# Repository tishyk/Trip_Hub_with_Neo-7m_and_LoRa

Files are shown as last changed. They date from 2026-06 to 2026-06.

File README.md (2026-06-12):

# LoRa GPS Mesh — off-grid trackers, chat & a live map dashboard

         

> A self-contained LoRa mesh that tracks GPS journeys, detects trips, relays
> chat, and reports device health — **with no internet, SIM card or cellular
> anywhere in the data path** — then visualises everything on a web map. This is cheap to build and easy to use.

<p align="center">
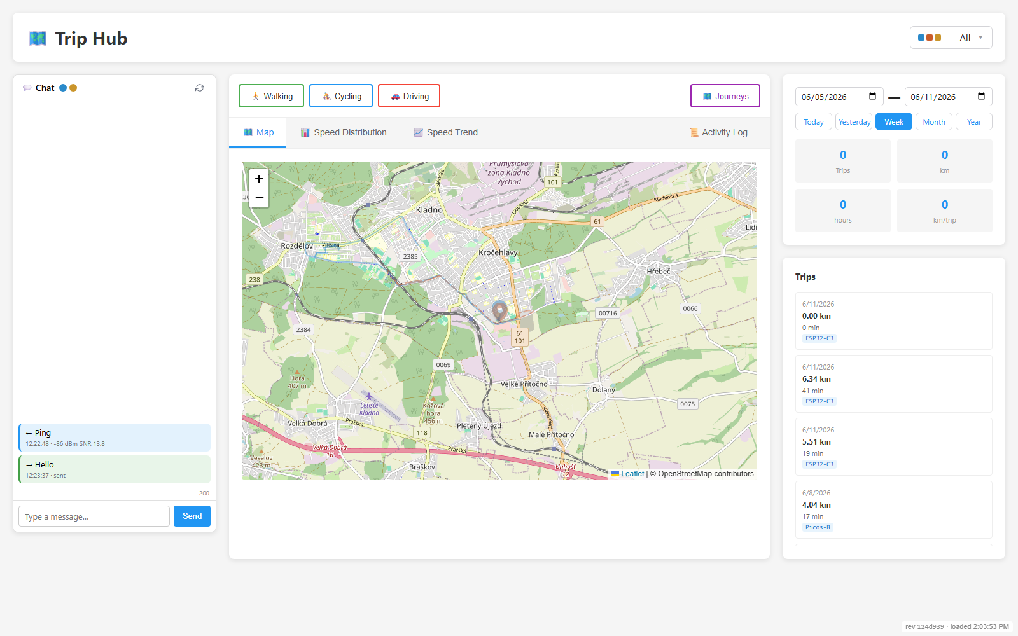
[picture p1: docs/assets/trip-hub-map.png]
Trip Hub web dashboard — live map with trip polylines, chat and presence
  
</p>

<p align="center">
  <em>The Trip Hub dashboard: show a live location, store a trip data points and build polinlines for 3 different types of movement, show stats, has an embedded chat panel with encripted comunication and live device-presence dots — fed entirely by 434 MHz LoRa radio. Support multiple devices with all actions logging</em>
</p>

---

## Why this exists

This is a working reference design for a question clients ask all the time:

> *“I want GPS tracking and a bit of messaging over long range, off the grid,
> shown on a web page — what can you actually build?”*

This repo is the answer, end to end: **four heterogeneous devices** speaking one
encrypted LoRa protocol, a Raspberry Pi gateway (or almost any other Linux OS), and **two web interfaces**
(an on-device captive chat UI and a full map/analytics dashboard). It’s built
from inexpensive, off-the-shelf modules and documents every wire format,
pinout and design decision so you can lift any piece into your own product.

It deliberately spans **three different runtimes** — Arduino C++, MicroPython
and CPython — to show the same radio protocol implemented natively on each, and
how a mixed fleet interoperates.

---

## Highlights

- 📡 **Long-range, license-free radio.** SX127x LoRa @ 434 MHz, SF9/BW125 —
  kilometres of range at a few hundred bits/s, no infrastructure.
- 🔒 **Encrypted on the air.** AES-128 on every packet; same key across the fleet.
- 🛰️ **GPS trip detection.** On-device state machine classifies walking /
  cycling / driving, detects start & stop, and logs dense tracks to flash.
- 🔁 **Store-and-forward sync.** Trackers buffer trips offline and stream them
  to the hub over a reliable query/response protocol when back in range.
- 💬 **Chat over LoRa.** Phone → on-device web UI → LoRa → hub, and back.
- 🟢 **Live device presence.** Every node heartbeats once a minute; the fleet
  (and both web UIs) shows who’s online, with signal strength.
- 🗺️ **Web dashboard.** Leaflet map of every journey, speed analytics, an
  activity log of raw radio traffic, and the chat panel — served from a Pi.
- 🧩 **Three runtimes, one protocol.** Arduino C++ (ESP32-C3), MicroPython
  (RP2040), CPython (Pi) — fully interoperable.

---

## The device lineup

| Device | Role | MCU / Host | Runtime | Radio | GPS | Web | Docs |
|---|---|---|---|---|---|---|---|
| **ESP32-C3 node** | GPS tracker **+ on-device WiFi chat UI** | ESP32-C3 | Arduino C++ | SX1278 | ✅ NEO-7M | ✅ softAP | [docs/esp32-c3.md](docs/esp32-c3.md) |
| **Pico B** | Battery GPS tracker (reference node) | RP2040 | MicroPython | SX1278 | ✅ NEO-7M | — | [docs/pico-b.md](docs/pico-b.md) |
| **Pico A** | LoRa ↔ Pi **bridge** + OLED hub UI | RP2040 | MicroPython | SX1278 | — | — | [docs/pico-a-bridge.md](docs/pico-a-bridge.md) |
| **Raspberry Pi 5** | Gateway server + **Trip Hub** web app | Pi 5 | CPython 3 | (via Pico A) | — | ✅ :5000 | [docs/trip-hub.md](docs/trip-hub.md) |

Each device is independently useful and documented as a standalone building
block. Pick the tracker, the bridge, the dashboard — or the whole stack.

### 3D-printed cases

Custom **Fusion 360** enclosures — print files (STL/3MF) on **Printables**
(links coming soon):

- **Pico A bridge** — pictured below; the two “eyes” are the HC-SR04 ultrasonic
  sensor (proximity wakes the OLED clock). 🔗 **Printables:** _coming soon_
- **ESP32-C3 tracker (AAA battery)** — _work in progress_; off-grid tracker with a
  AAA-battery compartment. 🔗 **Printables:** _coming soon_

<p align="center">
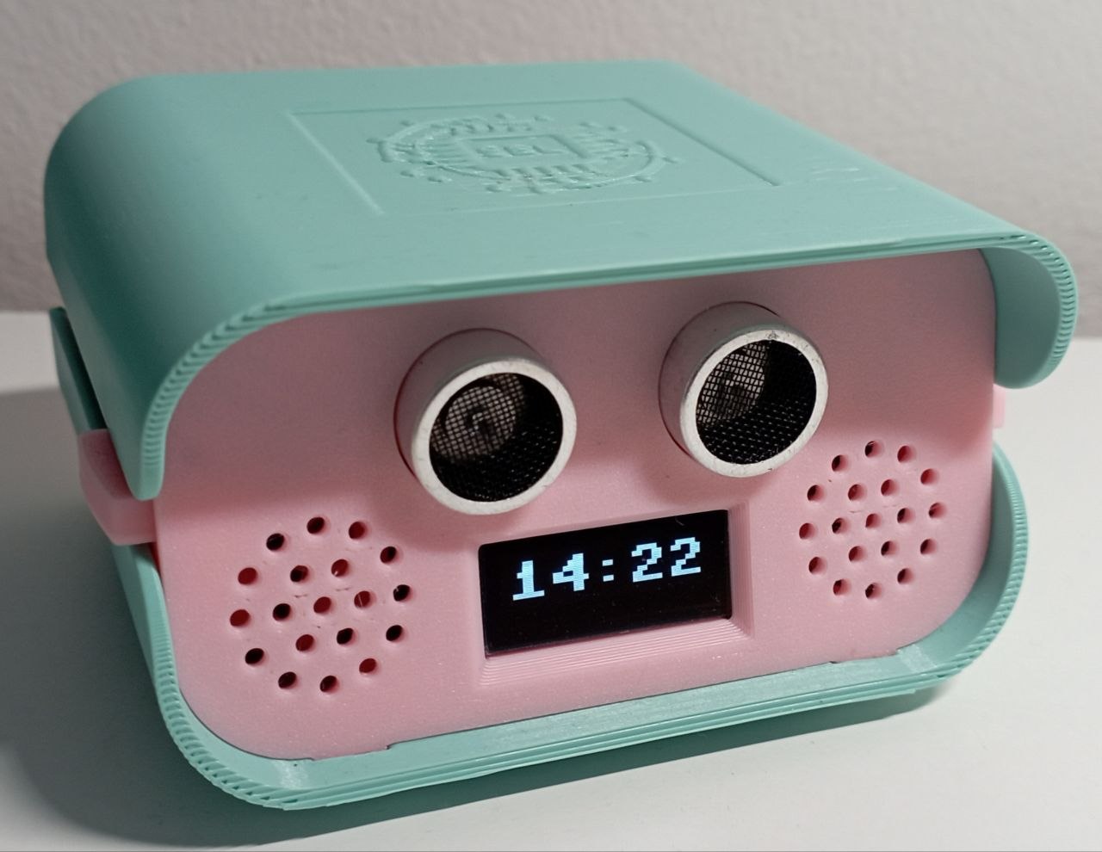
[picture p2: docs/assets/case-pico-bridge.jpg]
Pico A bridge — 3D-printed case with HC-SR04 sensor and OLED clock
  
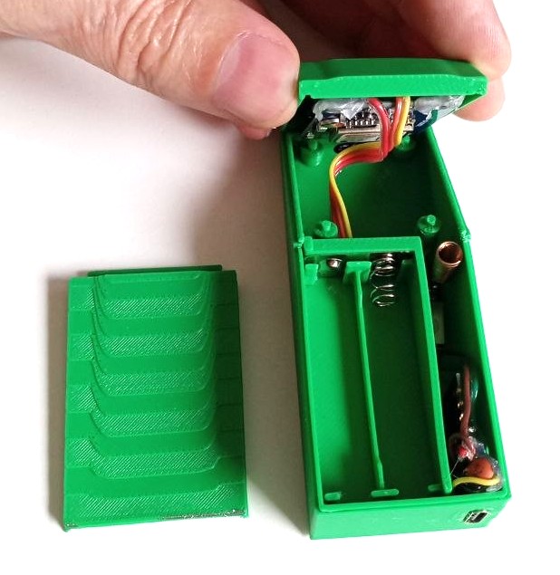
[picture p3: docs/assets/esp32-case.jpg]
ESP32-C3 AAA tracker case (work in progress) — internals
  
</p>
<p align="center"><sub>Left: Pico A bridge case · Right: ESP32-C3 AAA tracker case (WIP)</sub></p>

---

## How it fits together

<p align="center">
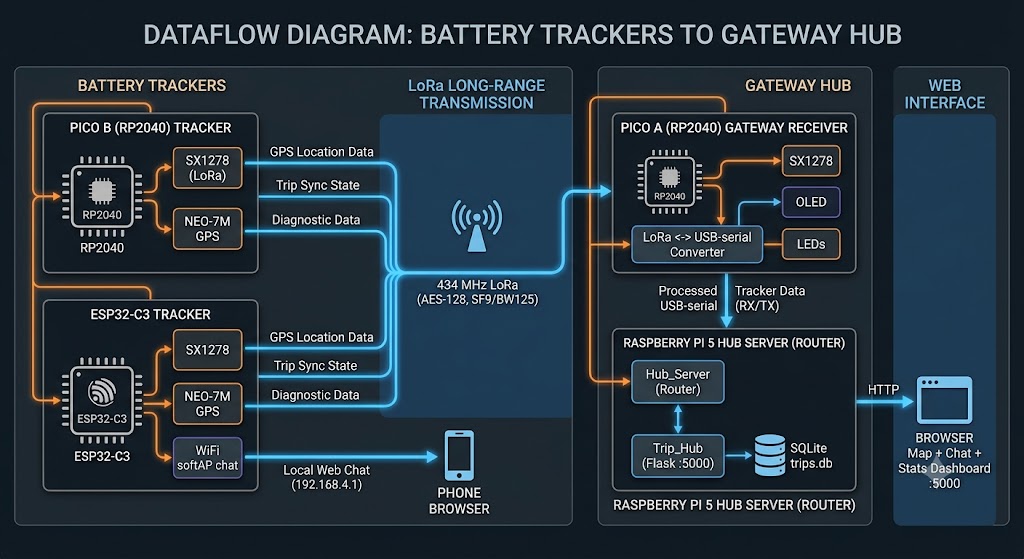
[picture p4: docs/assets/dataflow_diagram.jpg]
End-to-end data flow: battery trackers (Pico B, ESP32-C3) over 434 MHz LoRa (AES-128) to the Pico A bridge, into the Raspberry Pi 5 (Hub_Server + Trip_Hub), then out to the browser dashboard
  
</p>

- **Trackers** (Pico B, ESP32-C3) broadcast GPS, detect trips, and store them.
- **Pico A** is the only radio attached to the Pi: it bridges LoRa ⇄ USB serial,
  encrypting/decrypting and routing every packet, and drives a local OLED/LED UI.
- **Pi 5** runs `Hub_Server` (classifies and routes incoming traffic, drives the
  trip-sync protocol, persists to SQLite) and `Trip_Hub` (the Flask web app).

Full data-flow walkthrough: **[docs/architecture.md](docs/architecture.md)**.

---

## Communication protocols

Everything on the air is one of a small set of tagged, AES-encrypted text
payloads. A one-line taste:

| Prefix | Meaning |
|---|---|
| `GPS:` | periodic position broadcast (live map dot) |
| `TRIPSTART:` / `TRIPEND:` | trip lifecycle with metadata |
| `SYNC:` `QTRIPS:`/`RTRIPS:` `QTRIP:`/`RTRIP:` `QPTS:`/`RPTS:` `ACK:` | store-and-forward **trip sync** query/response |
| `CHAT:` | user chat message |
| `DEVICE:` | identity announce **+ 1-minute liveness heartbeat** |

Radio: **SX1276/78, 434.0 MHz, SF9, BW 125 kHz, CR 4/5, sync 0x34, CRC on,
preamble 8.** Crypto: **AES-128-ECB, PKCS7, 250 B max post-encryption.** The
USB-serial grammar between Pi and Pico A, the delta-compressed GPS fix packing,
and the full sync state machine are documented in
**[docs/protocols.md](docs/protocols.md)**.

You can watch the live protocol traffic in the dashboard’s Activity Log:

<p align="center">
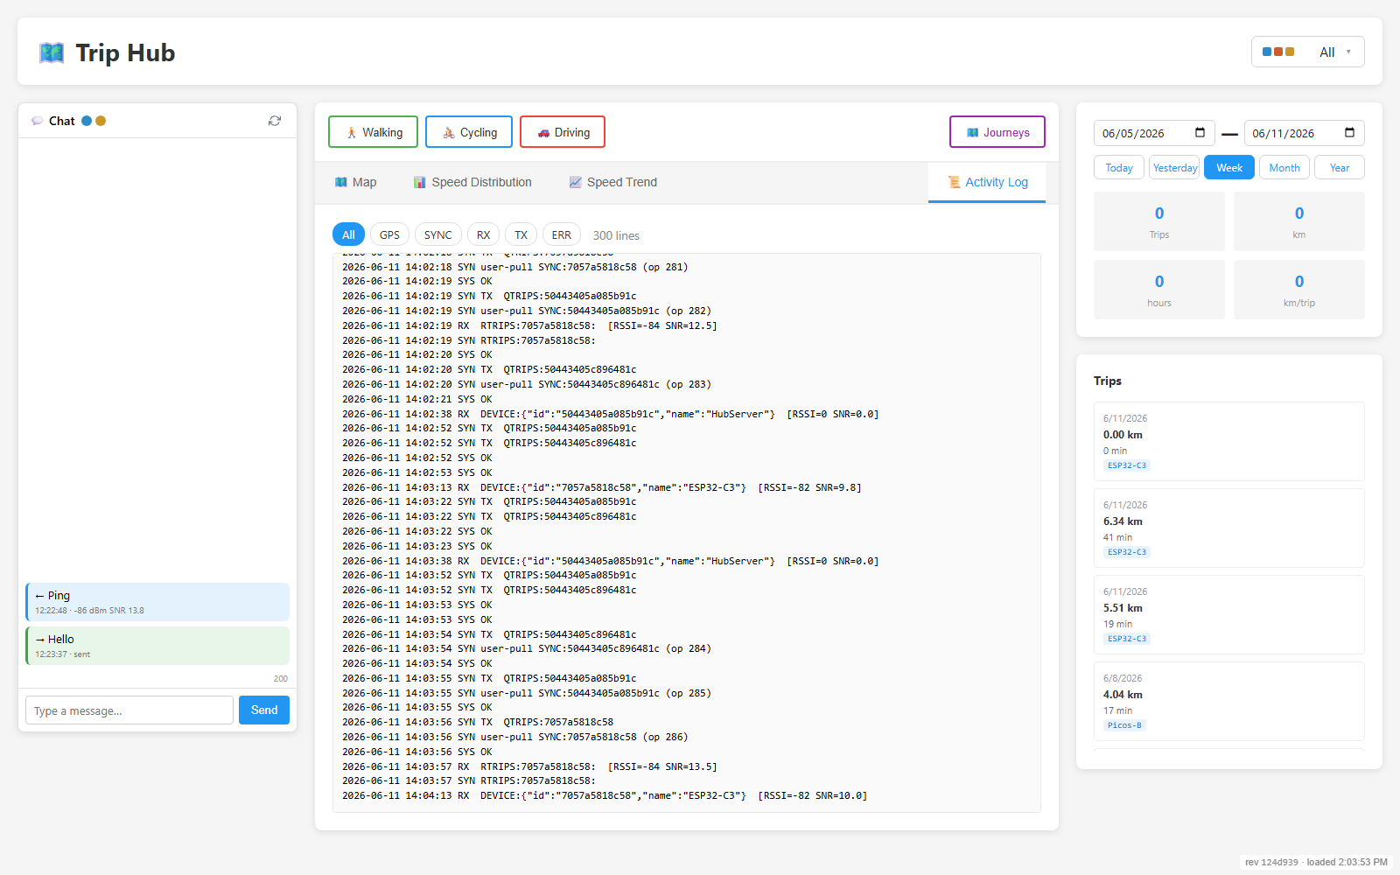
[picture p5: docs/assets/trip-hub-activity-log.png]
Live LoRa protocol traffic — DEVICE heartbeats, QPTS/RPTS/ACK trip sync
  
</p>

---

## Screenshots

| Live map & journeys | Chat + presence | Protocol activity log |
|---|---|---|
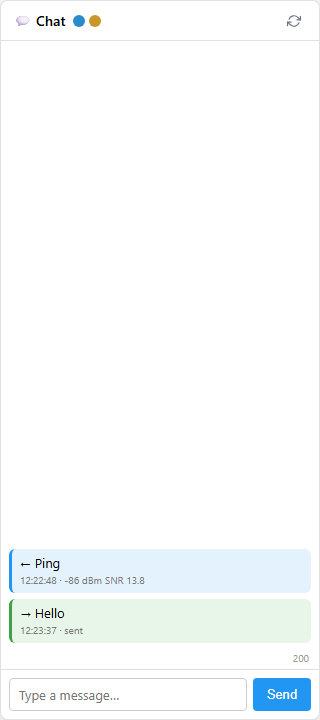
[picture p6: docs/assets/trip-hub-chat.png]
chat
| map |  | log |

And the **on-device ESP32 chat UI** — served from the tracker’s own WiFi softAP,
no Pi or internet — showing the live device-presence strip (`HubServer 7/10`):

<p align="center">
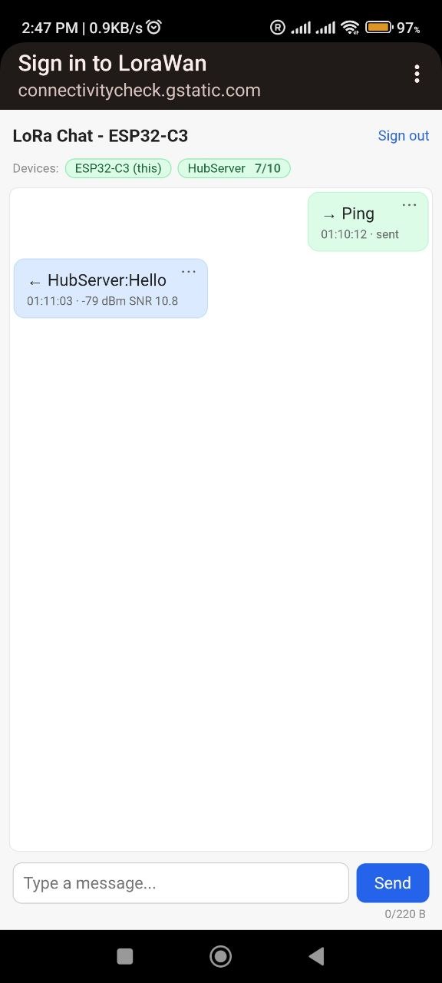
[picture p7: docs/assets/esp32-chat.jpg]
ESP32 on-device LoRa chat with device presence + signal strength
  
</p>

Full connect→chat walkthrough in **[docs/web-interfaces.md](docs/web-interfaces.md)**.

---

## Hardware

Built entirely from low-cost, widely available modules:

| Part | Used by | Docs / datasheet |
|---|---|---|
| **Ai-Thinker Ra-01 (SX1278)** LoRa | all nodes | [SX1278 product page](https://www.semtech.com/products/wireless-rf/lora-connect/sx1278) |
| **u-blox NEO-7M** GPS | trackers | [NEO-7 product page](https://www.u-blox.com/en/product/neo-7-series) |
| **ESP32-C3** (SuperMini) | ESP32 node | [ESP32-C3 product page](https://www.espressif.com/en/products/socs/esp32-c3) |
| **Raspberry Pi Pico (RP2040)** | Pico A / Pico B | [Raspberry Pi Pico](https://www.raspberrypi.com/products/raspberry-pi-pico/) |
| **Raspberry Pi 5** | gateway | [Raspberry Pi 5](https://www.raspberrypi.com/products/raspberry-pi-5/) |
| SSD1306 OLED, buttons, LEDs, DS1302 RTC | Pico A hub UI | — |

Full bill of materials, **wiring tables and pinouts** per device:
**[docs/hardware.md](docs/hardware.md)** — which also lists the **3D-printed
enclosures** (Fusion 360; Printables links coming soon) for the Pico A bridge and
a AAA-battery ESP32-C3 tracker.

---

## Quick start

> ⚠️ **Demo credentials.** This branch ships placeholder secrets (LoRa AES key
> `LoRaMeshDemoKey1`, WiFi password `ChangeMe-LoRa24`). **Change them before any
> real deployment** and keep the same AES key on every node — see
> [SECURITY.md](SECURITY.md).

### ESP32-C3 node (Arduino C++ / PlatformIO)
```bash
cd ESP32_C3
pio run -t upload          # build + flash over USB
# then join WiFi "LoraWan" and open http://192.168.4.1
```

### Pico A bridge / Pico B tracker (MicroPython)
```bash
# copy the project files to the Pico's flash, e.g. with mpremote:
mpremote connect <PORT> fs cp *.py :
mpremote connect <PORT> reset
```

### Raspberry Pi 5 gateway + dashboard (Python 3)
```bash
# 1. the LoRa<->serial router (talks to Pico A on /dev/ttyACM0)
cd Hub_Server   && python3 hub.py --server http://localhost:5000

# 2. the web dashboard
cd Trip_Hub     && python3 trip_server.py    # http://<pi-ip>:5000
```

Per-device build/run details live in each device’s doc page.

---

## Developer guide & tooling

Hands-on workflow for the fleet — connect, flash, read device data, inspect the
SQLite database, deploy to the bridge, capture dashboard screenshots:
**[docs/development.md](docs/development.md)**.

Sanitised dev scripts (dashboard screenshots, DB inspection, serial reader,
GPS-quality diagnostics) live in **[scripts/](scripts/)** — all driven by args /
env vars, no baked-in credentials.

---

## Repository layout

```
ESP32_C3/              Arduino C++ firmware — tracker + WiFi chat UI (PlatformIO)
PicoB/                 MicroPython — battery GPS tracker (reference node)
Hub_Server_Firmware/   MicroPython — Pico A LoRa<->serial bridge + OLED UI
Hub_Server/            Python 3 — Pi-side router, trip-sync engine, chat DB
Trip_Hub/              Python 3 — Flask map/chat/stats web app + SQLite
scripts/               Developer tooling (screenshots, DB inspect, serial, diagnostics)
docs/                  Architecture, protocols, hardware, developer guide, per-device guides
docs/assets/           Screenshots & images
```

Each top-level folder has its own `CLAUDE.md` with deeper, device-specific notes.

---

## What this repo demonstrates

For prospective clients, this is a portfolio of capabilities you can commission:

- Long-range, low-power, **infrastructure-free** telemetry (LoRa, not LoRaWAN —
  a private point-to-point/mesh protocol you fully own).
- **Application-layer encryption** on constrained MCUs.
- **GPS sensor fusion & motion classification** on-device (hysteresis,
  doppler-spike rejection, trip state machines).
- **Reliable store-and-forward** over a lossy link (offline buffering, batched
  delta-compressed transfer, ACK + retry, idempotent recovery).
- **Mixed-fleet interoperability** across C++, MicroPython and CPython.
- **Edge web UIs** (captive softAP) **and** a **cloud-free gateway dashboard**.
- Clean **device-identity & presence** management (rename-proof hardware IDs,
  heartbeats, signal-strength reporting).

---

## License

**PolyForm Noncommercial License 1.0.0** — see [LICENSE](LICENSE). Free for any
**noncommercial** use (personal, hobby, research, education, non-profits).
**Commercial use requires a separate license** from the author. Hardware names
and datasheets belong to their respective owners; links are for convenience.

---

<sub>Built as a demonstration of practical LoRa + GPS + web engineering.
Questions, or want something like this for your product? Open an issue.</sub>

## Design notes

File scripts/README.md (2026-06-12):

# Dev scripts

Cross-cutting developer tooling. Everything takes hosts / paths / ports via
**arguments or environment variables** — no credentials are baked in. See the
[developer guide](../docs/development.md) for the full workflow.

| Script | What it does | Example |
|---|---|---|
| [`capture_screenshots.py`](capture_screenshots.py) | Headless Playwright capture of the Trip Hub dashboard → `docs/assets/` | `BASE_URL=http://raspberrypi.local:5000 python scripts/capture_screenshots.py` |
| [`db_inspect.py`](db_inspect.py) | Quick SQLite read-out: latest trips, device presence, a trip’s point span | `python scripts/db_inspect.py --db /path/trips.db` |
| [`compare_trip_jumps.py`](compare_trip_jumps.py) | Fix-to-fix jump distribution per trip (GPS quality / outlier diagnostic) | `python scripts/compare_trip_jumps.py --db /path/trips.db 168 167` |
| [`read_serial.py`](read_serial.py) | Read a device’s serial output; `--no-reset` avoids rebooting the ESP32-C3 | `python scripts/read_serial.py COM9 --no-reset --seconds 6` |

## Prerequisites

```bash
pip install playwright pyserial && playwright install chromium
```
(`sqlite3` ships with Python.)

## Whole-Pi deploy

- [`../sync_pi5.sh`](../sync_pi5.sh) — one command to push `Hub_Server` /
  `Hub_Server_Firmware` / `Trip_Hub` to the Pi, flash Pico A via `mpremote`, and
  (re)start both tmux services. Configure via `$PI_HOST` / `$PI_DEPLOY_DIR`.

## Related per-project utilities & self-tests

- `PicoB/usb_dump_trips.py` — dump a tracker’s stored trips over USB (MicroPython).
- `PicoB/import_backup_trips.py` — POST archived `T*.gps/.json` trips to Trip_Hub.
- `PicoB/cleanup_short_trips.py` — prune short/noise trips on device + hub.
- `Hub_Server/recover_trip_from_log.py` — reconstruct a trip from `picoA_serial.log`.
- `python PicoB/sync_codec.py` · `sync_manager.py` · `trip_storage.py` ·
  `Hub_Server/splitter.py` — run any directly to execute its built-in self-tests.

> All host/path defaults in these scripts are placeholders
> (`raspberrypi.local`, `/home/pi/…`) — pass your own via flags/env.

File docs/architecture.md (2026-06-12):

# Architecture

How the four devices, two web UIs and one database fit together — and how a
GPS fix, a trip, a chat message and a heartbeat each travel through the system.

> See also: [protocols.md](protocols.md) for the exact wire formats,
> [hardware.md](hardware.md) for the parts and wiring.

## Nodes & responsibilities

<p align="center">
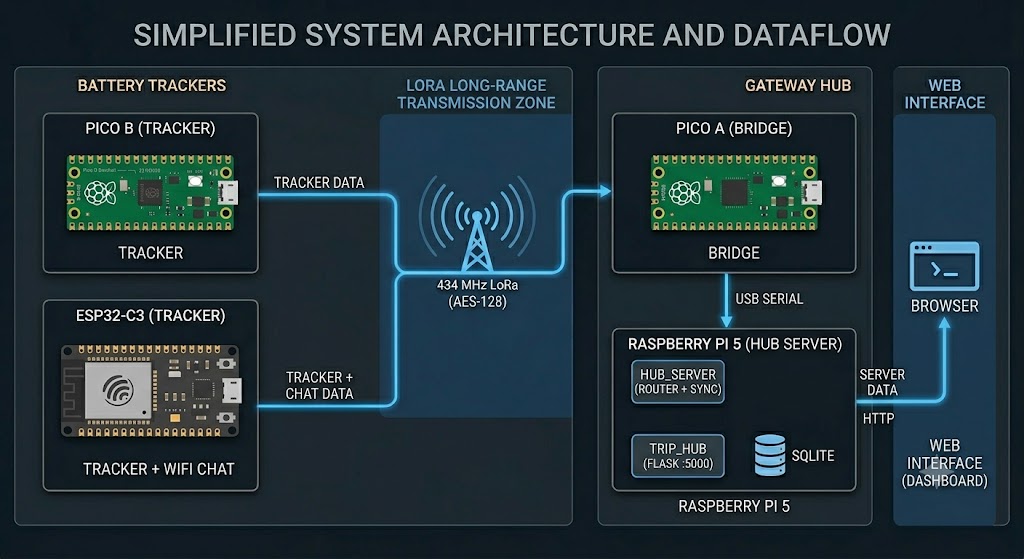
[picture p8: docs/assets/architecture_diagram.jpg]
Simplified system architecture and dataflow: battery trackers (Pico B, ESP32-C3) over the 434 MHz LoRa (AES-128) transmission zone to the Pico A bridge, into the Raspberry Pi 5 gateway hub (Hub_Server router+sync, Trip_Hub Flask :5000, SQLite), then out to the browser web interface
  
</p>

| Node | What it owns |
|---|---|
| **Pico B** | Battery tracker. GPS cadence, trip detection, on-flash trip log, store-and-forward sync. The *behavioural reference* the others mirror. |
| **ESP32-C3** | Same tracker role **plus** a WiFi softAP + on-device web chat UI so a phone can chat over LoRa with no Pi present. |
| **Pico A** | The fleet’s only radio attached to the Pi. Encrypts/decrypts, routes every LoRa packet to/from the Pi over USB serial, and drives a local OLED/LED/buzzer UI. |
| **Pi 5 · Hub_Server** | Classifies incoming traffic (GPS / trip / chat / sync / device), drives the trip-sync query/response engine, persists to SQLite, POSTs live data to Trip_Hub. |
| **Pi 5 · Trip_Hub** | Flask web app: Leaflet map, speed analytics, activity log, chat panel, device presence. Reads/writes the same SQLite DB. |

## The four data flows

### 1. Live position (`GPS:`)
```
tracker --GPS:{hwid,lat,lon,ts}--> (LoRa) --> Pico A --RX:--> Hub_Server
        --> splitter --> gps.log + HTTP POST /api/live_point --> Trip_Hub
        --> live_points table --> map "live dot"
```
Trackers broadcast a minimal position at a cadence chosen by movement class
(idle 60 s → driving 10 s). The hub never blocks on this; it just logs + forwards.

### 2. Trips (detect → store → sync)
A tracker runs an IDLE↔MOVING state machine. On stop-detect it finalises a trip
(distance, duration, avg/max speed, classification) and writes `.gps` (one fix
per line) + `.json` metadata to flash. Then it announces it has data, and the
**Pi pulls it** with a query/response handshake:

```
tracker: SYNC:<hwid>                         "I have unsent trips"
Pi  →    QTRIPS:<hwid>                        "list them"
tracker: RTRIPS:<hwid>:T123:88,T456:42        ids + point counts
Pi  →    QTRIP:T123                           "metadata for T123"
tracker: RTRIP:T123:{json}                    start/end/km/dur/type/...
Pi  →    QPTS:T123:0:11                        "points 0..11"
tracker: RPTS:T123:0:[[..delta-encoded..]]    a batch of fixes
   ... repeat QPTS/RPTS until all points received ...
Pi  →    ACK:T123                             "stored — you can delete it"
```
This is **reliable over a lossy link**: the Pi drives the cursor, re-requests on
loss, ignores duplicate/stale batches, and only ACKs (which deletes the trip on
the device) once every point is in the DB. See
[protocols.md → Trip sync](protocols.md#trip-sync-store-and-forward).

### 3. Chat (`CHAT:`)
```
phone → ESP32 web UI → CHAT:<sender>:<body> → (LoRa) → Pico A → Hub_Server
      → messages table → Trip_Hub chat panel
Pi → "TX:CHAT:HubServer:<text>" → Pico A → (LoRa) → all nodes
```
The ESP32 also keeps its own RAM+flash ring of the last 50 messages so its UI
works standalone. Pico A keeps the last 20 (persisted across reboot) for its OLED.

### 4. Presence / heartbeat (`DEVICE:`)
Every node re-broadcasts `DEVICE:{"id":<hwid>,"name":<name>}` once a minute.
The Pi treats an unchanged-name announce as a heartbeat and bumps
`devices.last_seen` (+ stores the bridge-heard RSSI). Both web UIs show who’s
online (10-minute window) and signal strength. The same `DEVICE:` message also
carries device renames and boot announces — one mechanism, three jobs. See
[protocols.md → Device identity & presence](protocols.md#device-identity--presence).

## Persistence (SQLite `trips.db`)

Shared by `Hub_Server` and `Trip_Hub`:

| Table | Holds |
|---|---|
| `trips` | one row per journey (times, start/end coords, km, duration, type, speeds, device) |
| `trip_points` | per-fix samples for a trip (lat, lon, ts, cumulative km, speed) |
| `live_points` | real-time `GPS:` broadcasts (the moving “you are here” dots) |
| `messages` | chat history (rx/tx, rssi/snr, source, status) |
| `devices` | identity roster: `id` (hwid) · `name` · `last_seen` · `last_rssi` |
| `journeys` / `journey_trips` | user-grouped multi-trip journeys |

## Process topology on the Pi

Two long-lived services (run under `tmux` in this deployment):

- `hub_server` → `python3 hub.py` — owns `/dev/ttyACM0` (Pico A), routes traffic.
- `trip_hub` → `python3 trip_server.py` — serves `:5000`, reads/writes the DB.

`Hub_Server` POSTs live points / trip events to `Trip_Hub` over local HTTP, so
the two stay decoupled and either can restart independently.

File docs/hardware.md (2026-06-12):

# Hardware

Bill of materials, wiring and pinouts for every node. All parts are common,
inexpensive and widely available.

> Photos: drop your own board shots into `docs/assets/` (suggested names below)
> and they’ll render here. Datasheet/vendor links are provided for each part.

## Bill of materials

| # | Part | Qty | Used by | Link |
|---|---|---|---|---|
| 1 | **Ai-Thinker Ra-01 — Semtech SX1278** LoRa module (433 MHz) | 3 | every radio node | [SX1278](https://www.semtech.com/products/wireless-rf/lora-connect/sx1278) · [Ra-01 docs](https://docs.ai-thinker.com/en/lora) |
| 2 | **u-blox NEO-7M** GPS module | 2 | Pico B, ESP32-C3 | [NEO-7](https://www.u-blox.com/en/product/neo-7-series) |
| 3 | **ESP32-C3 SuperMini** dev board | 1 | ESP32 node | [ESP32-C3](https://www.espressif.com/en/products/socs/esp32-c3) |
| 4 | **Raspberry Pi Pico (RP2040)** | 2 | Pico A, Pico B | [Pico](https://www.raspberrypi.com/products/raspberry-pi-pico/) · [RP2040 datasheet](https://datasheets.raspberrypi.com/rp2040/rp2040-datasheet.pdf) |
| 5 | **Raspberry Pi 5** | 1 | gateway | [Pi 5](https://www.raspberrypi.com/products/raspberry-pi-5/) |
| 6 | **SSD1306** 128×64 I²C OLED | 1 | Pico A UI | [SSD1306](https://cdn-shop.adafruit.com/datasheets/SSD1306.pdf) |
| 7 | **DS1302** RTC | 1 | Pico A clock | [DS1302](https://www.analog.com/media/en/technical-documentation/data-sheets/DS1302.pdf) |
| 8 | HC-SR04 ultrasonic, push buttons, status LEDs, buzzer, power bank | — | Pico A UI / tracker power | — |

LoRa antennas must be rated for **433 MHz**. Run the radios with an antenna
attached — transmitting into no load can damage the PA.

## Pinouts

### ESP32-C3 node ([../ESP32_C3/include/config.h](../ESP32_C3/include/config.h))
| Function | GPIO |
|---|---|
| LoRa SCK / MISO / MOSI / NSS / RST / DIO0 | 4 / 5 / 6 / 7 / 10 / 3 |
| GPS RX / TX (UART → NEO-7M) | 20 / 21 |

### Pico A — bridge / hub ([../Hub_Server_Firmware/config.py](../Hub_Server_Firmware/config.py))
| Function | GPIO |
|---|---|
| LoRa MISO / CS / SCK / MOSI / RST / DIO0 | 16 / 17 / 18 / 19 / 20 / 21 |
| OLED I²C SDA / SCL | 0 / 1 |
| DS1302 CLK / DAT / RST | 2 / 3 / 4 |
| Buzzer | 5 |
| LEDs (G/B/R · R/B/G) | 6,7,8 · 9,10,11 |
| Buttons L / R | 12 / 13 |
| HC-SR04 TRIG / ECHO | 14 / 15 |

### Pico B — battery tracker ([../PicoB/config.py](../PicoB/config.py))
| Function | GPIO |
|---|---|
| LoRa SCK / MOSI / MISO / NSS / RST / DIO0 | 2 / 3 / 4 / 5 / 22 / 26 |
| GPS UART → NEO-7M | per `config.py` |

> Note the two RP2040 boards use **different** LoRa pinouts (Pico A vs Pico B) —
> wire each to its own table.

## Power notes

- The Ra-01 draws **~120 mA on TX**. On the ESP32-C3 especially, decouple VCC/GND
  with **100 nF + 100 µF** close to the module; an under-powered rail causes resets
  mid-transmit (the firmware now recovers interrupted trips on reboot, but clean
  power avoids the resets entirely).
- Pico B is designed to run headless from a USB power bank.

## Enclosures (3D-printed)

Custom cases designed in **Fusion 360** for this project. Print files (STL/3MF)
will be published on **Printables** — links coming soon.

### Pico A bridge case
Enclosure for the Pico A LoRa↔serial bridge (Pico + Ra-01 + OLED/LEDs/buttons).

- 🔗 **Printables:** _coming soon_

Pico A bridge case (HC-SR04 "eyes", OLED clock)
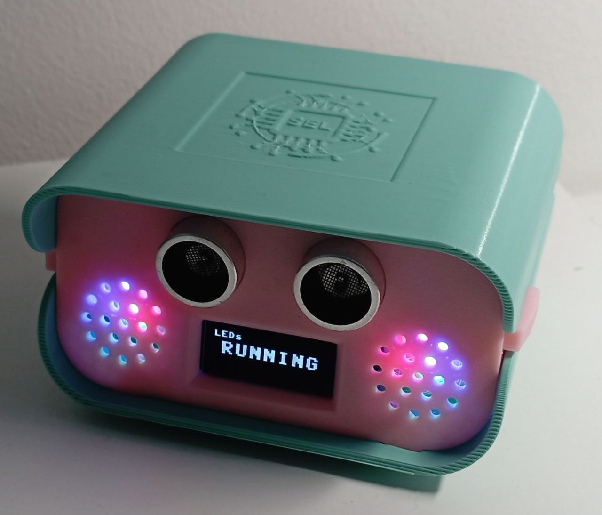
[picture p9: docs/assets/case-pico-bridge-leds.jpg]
Pico A bridge case — RGB LEDs running


### ESP32-C3 tracker case (AAA battery) — _work in progress_
A portable enclosure for the ESP32-C3 node with a **AAA battery** compartment —
fully off-grid GPS tracking. **Work in progress**; print files will be published
on **Printables** (link coming soon).

ESP32-C3 AAA tracker case — open, showing ESP32-C3, GPS module and battery bay
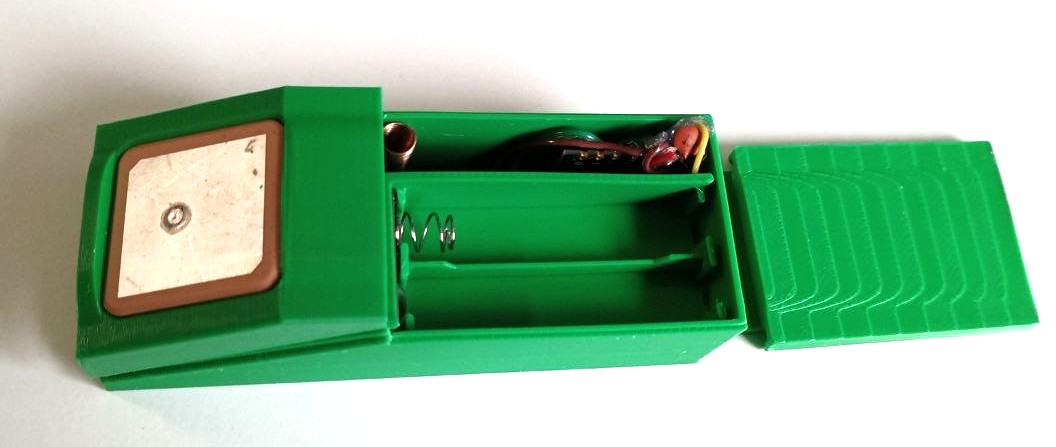
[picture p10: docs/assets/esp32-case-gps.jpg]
ESP32-C3 AAA tracker case — GPS patch antenna end + battery bays


## Suggested photo filenames (optional)

Drop these into `docs/assets/` to enrich the docs:

```
hw-esp32c3-node.jpg        ESP32-C3 + Ra-01 + NEO-7M wired
hw-picoa-bridge.jpg        Pico A + OLED + LEDs + buttons
hw-picob-tracker.jpg       Pico B battery tracker
hw-pi5-gateway.jpg         Pi 5 with Pico A attached
```

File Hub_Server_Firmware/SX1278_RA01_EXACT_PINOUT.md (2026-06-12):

# SX1278 / Ra-01 LoRa Module - Exact Pinout Guide

## Your Modules Identified ✅

**Image 1:** SX1278 LoRa Module (Blue board)
- Large spiral antenna coil
- 8 pin header
- 410-525 MHz FSK
- Perfect for Trip Tracker!

**Image 2:** Ra-01 Module (Tiny black square)
- Compact version
- Same SX1278 chip inside
- 8 pins (smaller header)
- Same pinout!

## Exact Pin Configuration

### SX1278 Module Pins (Left to Right)

```
Pin 1  → GND
Pin 2  → MOSI (DIN)
Pin 3  → MISO (DOUT)
Pin 4  → SCK (CLK)
Pin 5  → NSS/CS
Pin 6  → RESET
Pin 7  → DIO0
Pin 8  → 3.3V
```

### Ra-01 Module Pins (Same Layout)

```
Pin 1  → GND
Pin 2  → MOSI
Pin 3  → MISO
Pin 4  → SCK
Pin 5  → NSS/CS
Pin 6  → RESET
Pin 7  → DIO0
Pin 8  → 3.3V
```

## Wiring to Raspberry Pi Pico

```
SX1278/Ra-01    →    Pico RP2040
════════════════════════════════

Pin 1 (GND)     →    GND (Pin 3, 8, 13, 18, 23, 28, 33, 38)
Pin 2 (MOSI)    →    GPIO 3 (SPI0 MOSI) - Pin 7
Pin 3 (MISO)    →    GPIO 4 (SPI0 MISO) - Pin 6
Pin 4 (SCK)     →    GPIO 2 (SPI0 SCK)  - Pin 4
Pin 5 (NSS/CS)  →    GPIO 5 (SPI0 CS)   - Pin 9
Pin 6 (RESET)   →    GPIO 22            - Pin 29
Pin 7 (DIO0)    →    GPIO 26 (INT/IRQ)  - Pin 31
Pin 8 (3.3V)    →    3V3 (Pin 36)
```

## Pico Pinout Reference

```
Pico RP2040 Top View
════════════════════

GPIO0   GPIO1   GND     GPIO2   GPIO3   GPIO4
 1      2       3       4       5       6     
[SCK0] [MOSI0] [GND]  [SCK0]  [MOSI0] [MISO0]
                                            ↓ Pin 6
                                       [GPIO 4 - MISO]

GPIO5   GPIO6   GPIO7   GPIO8   GPIO9   GPIO10
 7      8       9      10      11       12
[NSS0]  ...     ...     ...     ...      ...
   ↓ Pin 9
 [GPIO 5 - CS]

...

GPIO22  GPIO23  GPIO24  GPIO25  GPIO26  GPIO27
29      30      31      32      33      34
[RST]  [RX]    [TX]    [DEBUG] [INT]   ...
  ↓ Pin 29      ↓ Pin 31
[GPIO 22]   [GPIO 26 - DIO0]

...

3V3     GND
36      38
[3.3V]  [GND]
```

## Complete Wiring Table

| SX1278 Pin | Function | Pico Pin | GPIO | Purpose |
|---|---|---|---|---|
| 1 | GND | 3, 8, 13, 18, 23, 28, 33, 38 | - | Ground |
| 2 | MOSI | 7 | GPIO 3 | SPI Data In |
| 3 | MISO | 6 | GPIO 4 | SPI Data Out |
| 4 | SCK | 4 | GPIO 2 | SPI Clock |
| 5 | NSS/CS | 9 | GPIO 5 | SPI Chip Select |
| 6 | RESET | 29 | GPIO 22 | Reset Signal |
| 7 | DIO0 | 31 | GPIO 26 | Interrupt/RX Done |
| 8 | 3.3V | 36 | - | Power Supply |

## Wiring Diagram (Text)

```
┌─────────────────────┐
│ SX1278 Module       │
│  (Blue Board)       │
├─────────────────────┤
│ 1 GND    ─────────→ GND (Pico Pin 3)
│ 2 MOSI   ─────────→ GPIO 3 (Pico Pin 7)
│ 3 MISO   ─────────→ GPIO 4 (Pico Pin 6)
│ 4 SCK    ─────────→ GPIO 2 (Pico Pin 4)
│ 5 NSS/CS ─────────→ GPIO 5 (Pico Pin 9)
│ 6 RESET  ─────────→ GPIO 22 (Pico Pin 29)
│ 7 DIO0   ─────────→ GPIO 26 (Pico Pin 31)
│ 8 3.3V   ─────────→ 3V3 (Pico Pin 36)
└─────────────────────┘
     ↓
   Antenna Coil
```

## Python Code for This Module

```python
from machine import SPI, Pin
from sx127x_fsk import SX127xFSK
import time

# SPI Configuration
spi = SPI(0, 
    baudrate=10000000,
    polarity=0,
    phase=0,
    bits=8,
    firstbit=SPI.MSB,
    sck=Pin(2),
    mosi=Pin(3),
    miso=Pin(4)
)

# Pin Definitions (Exact)
pins = {
    'ss': 5,        # GPIO 5 (NSS/CS)
    'rst': 22,      # GPIO 22 (RESET)
    'dio_0': 26,    # GPIO 26 (DIO0)
}

# Module Parameters
parameters = {
    'frequency': 433E6,           # 433 MHz
    'tx_power_level': 15,         # 15 dBm
    'bit_rate': 9600,             # 9600 bps
    'frequency_deviation': 5000,  # 5 kHz
    'bandwidth': 50000,           # 50 kHz
    'preamble_length': 16,        # 16 bytes
    'sync_word': 0x2d,            # 0x2D
    'enable_CRC': True,
}

# Initialize Module
print("Initializing SX1278 module...")
lora = SX127xFSK(spi, pins, parameters)
print("✅ Module ready!")

# Send Test
print("Sending test message...")
lora.println("Hello from Pico!")
print("✅ Sent!")

# Receive Test
print("Listening for 10 seconds...")
lora.receive()
start_time = time.time()

while time.time() - start_time < 10:
    if lora.received_packet():
        payload = lora.read_payload()
        rssi = lora.packet_rssi()
        print(f"✅ Received: {payload.decode()}")
        print(f"   RSSI: {rssi} dBm")
    time.sleep(0.1)

print("Test complete!")
```

## Physical Assembly Tips

### Soldering
1. **Clean pins** with desoldering wick if needed
2. **Pre-tin** all pins (add small solder blob)
3. **Use flux** for better solder flow
4. **Heat both wire and pad** (2-3 seconds)
5. **Use thin solder** (0.5mm or smaller)
6. **Check for shorts** with multimeter

### Cable Management
```
Use a breakout board if available:
━━━━━━━━━━━━━━━━━━━━━━
   [SX1278 Module]
        ↓
   [Breakout Board]
        ↓
  [To Pico via ribbon]
```

Or use individual wires:
- **Colored wires** (easier to track)
- **Heatshrink tubing** (prevent shorts)
- **Label each wire** (avoid confusion)

### Antenna
- **Keep antenna coil clear** (no obstacles)
- **Orient perpendicular** to other antennas
- **17cm long wire** (optimal for 433 MHz)
- **Keep away from metal** (use plastic case)

## Testing Checklist

```
Before using with Trip Tracker:

Hardware:
☐ All 8 wires connected correctly
☐ No cold solder joints
☐ No shorts (test with multimeter)
☐ Power LED on (if present)
☐ Antenna coil intact

Software:
☐ SPI works (read version register)
☐ Can transmit (serial output shows "Sent")
☐ Can receive (with second module)
☐ RSSI shows reasonable values (-120 to 0 dBm)
☐ No error messages in console

Communication:
☐ Both modules same frequency (433 MHz)
☐ Both modules same bit rate (9600)
☐ Both modules same sync word (0x2d)
☐ Range at least 100 meters
☐ No data corruption in messages
```

## Troubleshooting Quick Reference

| Problem | Solution |
|---|---|
| Module not detected | Check all 8 wires connected |
| SPI errors | Verify GPIO 2,3,4,5 are free |
| No transmission | Check DIO0 pin (GPIO 26) |
| No reception | Swap RX/TX or check sync word |
| Short range (<10m) | Raise TX power to 20 dBm |
| Interference | Lower TX power to 10 dBm |
| Checksum errors | Enable CRC on both sides |

## Integration with Trip Tracker

Just use the code exactly as shown above, then in `trip_tracker_enhanced.py`:

```python
from sx127x_fsk import SX127xFSK

# Paste the initialization code above
# Then use:

# Send event
lora.println("Trip started: WALKING")

# Or with JSON
import json
event = {'type': 'TRIP_START', 'movement': 'WALKING'}
lora.println(json.dumps(event))
```

## Summary

✅ **Modules:** SX1278 / Ra-01 (both work!)
✅ **Frequency:** 433 MHz ISM band
✅ **Interface:** SPI (standard)
✅ **Pins:** Exactly as shown above
✅ **Driver:** sx127x_fsk.py
✅ **Range:** 5-10 km line-of-sight
✅ **Speed:** 9600 bps
✅ **Power:** 15 dBm recommended

Your exact module is **100% compatible** with Trip Tracker! 🚀

Just follow the wiring above and you're good to go!

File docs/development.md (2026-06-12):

# Developer guide

How to connect to, flash, inspect and deploy every device in the fleet — plus
the data you’ll want while developing. This doubles as the operating manual for
automated assistants (e.g. Claude Code) working in this repo.

> **Credentials & hosts are placeholders.** Set these for your own setup; never
> commit real values (see [../SECURITY.md](../SECURITY.md)).
>
> ```bash
> export PI_HOST=raspberrypi.local        # your Pi's hostname or IP
> export PI_USER=pi                        # your Pi login
> export PI_DIR=/home/$PI_USER/esp32_projects   # deploy dir on the Pi
> export DB=$PI_DIR/Trip_Hub/trips.db      # SQLite path on the Pi
> ```
> A convenient `~/.ssh/config` alias keeps commands short:
> ```
> Host pi   HostName raspberrypi.local   User pi
> ```
> Serial ports differ by OS: **Windows** `COM3`, `COM9`, … · **Linux/macOS**
> `/dev/ttyACM0`, `/dev/tty.usbmodem*`.

## Toolchains

| Tool | For | Install |
|---|---|---|
| **PlatformIO** | ESP32-C3 build/flash | `pip install platformio` (or VS Code extension) |
| **mpremote** | MicroPython Picos | `pip install mpremote` |
| **Python 3** | Pi services, scripts | system / `python.org` |
| **pyserial** | reading device serial | `pip install pyserial` |
| **Playwright** | dashboard screenshots | `pip install playwright && playwright install chromium` |
| **sqlite3** | DB inspection | bundled with Python (`import sqlite3`) or the CLI |

---

## ESP32-C3 (Arduino C++)

**Connect:** USB-C; it enumerates as a USB serial device. **Note:** the C3 uses
native USB — toggling DTR/RTS resets it, so a naive serial open reboots the board
(use [`scripts/read_serial.py --no-reset`](../scripts/read_serial.py)).

```bash
cd ESP32_C3
pio run                                  # compile
pio run -t upload                        # flash (preserves LittleFS!)
pio run -t upload --upload-port COM9     # pin the port if needed
pio device monitor -b 115200             # serial console
```
A plain `upload` rewrites only the app partition — **trips/chat on LittleFS
survive**. Avoid “Erase Flash” / “Upload Filesystem Image” unless you mean it.

**Read its data over WiFi** (join AP `LoraWan`, then):
```bash
curl http://192.168.4.1/api/devices       # liveness roster + signal
curl http://192.168.4.1/api/trips          # trips on flash
curl "http://192.168.4.1/api/trip?id=T1749330565"   # one trip + fixes
```

---

## MicroPython Picos (Pico A bridge, Pico B tracker)

```bash
PORT=/dev/ttyACM0                          # or COMx on Windows
mpremote connect $PORT fs ls               # list flash
mpremote connect $PORT fs cp *.py :        # deploy all modules
mpremote connect $PORT fs cp file.py :file.py
mpremote connect $PORT fs cat sync_state.json
mpremote connect $PORT reset               # restart into new code
mpremote connect $PORT repl                # interactive REPL (Ctrl-] to exit)
```

**Dump a tracker’s trips over USB** (Pico B):
```bash
mpremote connect $PORT run PicoB/usb_dump_trips.py
```

> Only one process can own a Pico’s serial port. If the Pi’s bridge driver
> (`hub.py`) is running, stop it before `mpremote` (see *Deploying to Pico A*).

---

## Raspberry Pi 5 gateway

```bash
ssh $PI_USER@$PI_HOST          # or: ssh pi   (with the alias above)
```

Two long-lived services (run here under `tmux`):

```bash
# router / LoRa bridge driver (owns the Pico A serial port)
tmux new-session -d -s hub_server -c $PI_DIR/Hub_Server \
    "python3 hub.py --server http://localhost:5000"

# web dashboard
tmux new-session -d -s trip_hub   -c $PI_DIR/Trip_Hub \
    "python3 trip_server.py"           # http://$PI_HOST:5000

tmux ls                                  # what's running
tmux capture-pane -t hub_server -p | tail -40   # recent router output
```
Restart either independently; **both must be up** (it’s easy to restart the
router and forget the web app on `:5000`). Logs live in `Hub_Server/logs/`.

---

## Inspecting the data (SQLite)

```bash
# latest trips with point counts and sync status
ssh pi "sqlite3 $DB 'SELECT id, device_id, start_time, end_time, distance_km,
        movement_type, (SELECT COUNT(*) FROM trip_points tp WHERE tp.trip_id=t.id)
        AS npts, sync_status FROM trips t ORDER BY id DESC LIMIT 12;'"

# device roster / presence (drives the chat dots)
ssh pi "sqlite3 $DB 'SELECT name, id, last_seen, last_rssi FROM devices ORDER BY name;'"

# point span for one trip
ssh pi "sqlite3 $DB 'SELECT MIN(timestamp), MAX(timestamp), COUNT(*)
        FROM trip_points WHERE trip_id=168;'"
```
Or, locally with the helper: [`scripts/db_inspect.py`](../scripts/db_inspect.py).

The dashboard’s **Activity Log** tab (`http://$PI_HOST:5000`) is the live view of
decrypted radio traffic (`DEVICE:` heartbeats, `QPTS`/`RPTS`/`ACK`, `SYNC`).

---

## Deploying to Pico A (the bridge)

Pico A is attached to the Pi and its serial port is held by `hub.py`, so:

```bash
ssh pi '
  MPR=~/.local/bin/mpremote
  tmux kill-session -t hub_server                 # free /dev/ttyACM0
  sleep 2
  cd '"$PI_DIR"'/Hub_Server_Firmware
  $MPR connect /dev/ttyACM0 fs cp lora_bridge.py :lora_bridge.py
  $MPR connect /dev/ttyACM0 reset
  tmux new-session -d -s hub_server -c '"$PI_DIR"'/Hub_Server \
      "python3 hub.py --server http://localhost:5000"
'
```

---

## Screenshots of the dashboard

```bash
BASE_URL=http://$PI_HOST:5000 python scripts/capture_screenshots.py
# writes docs/assets/trip-hub-*.png
```
The ESP32 UI lives on its own softAP, so capture those from a device joined to
`LoraWan` (see [web-interfaces.md](web-interfaces.md)).

---

## Built-in self-tests (no hardware)

Several modules self-test when run directly:

```bash
python PicoB/sync_codec.py        # RPTS delta codec round-trips
python PicoB/sync_manager.py      # sync state machine against a fake DB
python PicoB/trip_storage.py      # trip storage + resume logic
python Hub_Server/splitter.py     # payload routing / GPS+trip parsing
```

---

## Dev scripts

Cross-cutting tooling lives in [`scripts/`](../scripts/) — see
[scripts/README.md](../scripts/README.md). All take hosts/paths via args or env
so there are no baked-in credentials.

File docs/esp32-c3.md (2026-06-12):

# ESP32-C3 node — GPS tracker + on-device WiFi chat

The most capable node: a LoRa GPS tracker **and** a self-hosted WiFi access point
serving a web chat UI, so a phone can talk over LoRa with no Pi in the loop.

| | |
|---|---|
| **Folder** | [../ESP32_C3/](../ESP32_C3/) |
| **MCU / board** | ESP32-C3 (`esp32-c3-devkitm-1`) |
| **Runtime** | Arduino C++ via **PlatformIO** |
| **Radio / GPS** | SX1278 (RadioLib) · NEO-7M (TinyGPSPlus) |
| **Filesystem** | LittleFS |
| **Pinout** | [hardware.md → ESP32-C3](hardware.md#esp32-c3-node-esp32_c3includeconfigh) |
| **Case** | AAA-battery enclosure — _work in progress_; STL on Printables, _coming soon_ |

ESP32-C3 on-device LoRa chat UI with device-presence strip and signal score
ESP32-C3 AAA tracker case (work in progress) — ESP32-C3, GPS and battery bay

## What it does

- **GPS trip detection** — IDLE↔MOVING state machine with start/stop detection,
  speed-class classification (walking/cycling/driving), doppler-spike-hardened
  max speed, and a retroactive motion buffer so a trip’s start coordinate is the
  real departure point.
- **Adaptive GPS cadence** — broadcast interval follows movement class with
  hysteresis (idle 60 s → driving 10 s).
- **On-flash trip log** — `/trips/T<ts>.gps` (one fix per line) + `.json` meta,
  plus `in_progress.txt`. Survives reboots; a trip interrupted by a reset is
  rebuilt from its fixes on next boot.
- **Store-and-forward sync** — answers the Pi’s `QTRIPS/QTRIP/QPTS` queries and
  deletes a trip only on `ACK`.
- **WiFi softAP + web chat** — SSID `LoraWan`, UI at `http://192.168.4.1`; the
  page prepends `CHAT:` and TXes over LoRa. Last 50 messages mirrored to flash.
- **Presence** — broadcasts a `DEVICE:` heartbeat every 60 s and keeps a roster
  of peers it hears, exposed at `/api/devices` and shown as on/offline chips with
  a signal score.

## Source layout ([../ESP32_C3/src/](../ESP32_C3/src/))

| File | Role |
|---|---|
| `main.cpp` | boot, main loop, trip pipeline, RX dispatch, heartbeat |
| `lora_radio.cpp` | RadioLib SX1278 driver + TX/RX |
| `crypto.cpp` | AES-128-ECB + PKCS7 (key from `config.h`) |
| `net.cpp` | WiFi softAP |
| `web_server.cpp` | HTTP chat UI + `/api/messages`, `/api/send`, `/api/devices`, `/api/trips`, `/api/trip` |
| `chat_log.cpp` | RAM ring + LittleFS mirror of chat |
| `gps.cpp` | NMEA → fix struct |
| `trip_tracker.cpp` | trip detection state machine |
| `trip_storage.cpp` | `.gps`/`.json` flash storage + sync state |
| `sync_manager.cpp` | trip-sync responder |
| `sync_codec.cpp` | RPTS delta encode/decode |
| `presence.cpp` | liveness roster (peers + signal) |
| `include/config.h` | **all tunables**: pins, radio params, AES key, WiFi, cadence, trip thresholds |

## HTTP API (behind the softAP, auth-gated)

| Endpoint | Returns |
|---|---|
| `GET /` | chat web UI |
| `GET /api/messages?since=N` | chat messages |
| `POST /api/send` | send a chat message |
| `GET /api/devices` | liveness roster `[{name,hwid,age,online,self,rssi}]` |
| `GET /api/trips` | trips on flash `[{id,npts,sync}]` |
| `GET /api/trip?id=T…` | one trip’s metadata + full fix array |

## Build & flash

```bash
cd ESP32_C3
pio run                 # compile
pio run -t upload       # flash over USB
pio device monitor      # serial @ 115200
```
A plain firmware upload **preserves LittleFS** (your trips/chat survive). Set a
device name at build time with `-DDEVICE_ID=\"C1\"` in `platformio.ini` if needed.

## Gotchas

- After `transmit()` RadioLib leaves the chip in standby — always re-arm
  `startReceive()` (already handled in `lora_radio.cpp`).
- Keep the RadioLib RX ISR tiny (just sets a flag).
- Ra-01 TX current can brown out a weak rail → reset. Decouple well; the boot
  trip-finalizer recovers data either way.

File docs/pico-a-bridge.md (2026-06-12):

# Pico A — LoRa ↔ Pi bridge + hub UI

The fleet’s only radio attached to the gateway. It’s a transparent, encrypting
modem between LoRa and the Pi’s USB serial, and it drives a local OLED/LED/buzzer
status UI.

| | |
|---|---|
| **Folder** | [../Hub_Server_Firmware/](../Hub_Server_Firmware/) |
| **MCU** | Raspberry Pi Pico (RP2040) |
| **Runtime** | MicroPython |
| **Radio** | SX1278 (bespoke register driver) |
| **Peripherals** | SSD1306 OLED, LEDs, buzzer, DS1302 RTC, buttons, HC-SR04 |
| **Pinout** | [hardware.md → Pico A](hardware.md#pico-a--bridge--hub-hub_server_firmwareconfigpy) |
| **Case** | 3D-printed (Fusion 360) — STL on Printables, _coming soon_ |

Pico A bridge — 3D-printed case (HC-SR04 "eyes", proximity-wake OLED clock)
Pico A bridge — RGB status LEDs running, OLED message

## What it does

- **Bridge** — decrypts incoming LoRa frames and forwards them to the Pi as
  `RX:<text>|<rssi>|<snr>`; encrypts `TX:<text>` from the Pi and transmits.
- **Router** — classifies each packet and gives it the right treatment:
  `GPS:`/`TRIPSTART:`/`TRIPEND:`/`SYNC:`/`R*:` → forward to Pi; `QTRIPS:`/`QTRIP:`/
  `QPTS:`/`ACK:` (from Pi) → encrypt + relay over LoRa; `CHAT:` → OLED + history +
  forward (+ auto-`PONG`); `DEVICE:` → heartbeat note + forward.
- **Hub presence** — announces itself as `HubServer` every 60 s (over LoRa for
  peers, and up to the Pi so it appears in the device roster).
- **Local UI** — OLED clock/notifications, RX blink LEDs, buzzer alerts, a
  scrollable history of the **last 20 chat messages** (persisted across reboot),
  GPS-fix indicator, button navigation, RTC.

## Source layout ([../Hub_Server_Firmware/](../Hub_Server_Firmware/))

| File | Role |
|---|---|
| `main.py` | boot, wires modules, runs the loop |
| `lora.py` | raw SX1278 driver (SPI register pokes) |
| `lora_bridge.py` | LoRa ⇄ serial routing, AES, dedup, heartbeat |
| `serial_io.py` | USB serial parse/dispatch |
| `messages.py` | last-N chat ring (flash-persisted) |
| `storage.py` | persistent event log on flash |
| `ui.py` / `display.py` / `leds.py` / `buttons.py` | OLED + LEDs + buttons |
| `clock_rtc.py` / `time_sync.py` | DS1302 RTC |
| `config.py` | pin map, AES key, LoRa air params |

## USB-serial grammar

See [protocols.md → Pi ⇄ Pico A](protocols.md#pi--pico-a-usb-serial). In short:
`TX: / PING / RESET / TIME:` down, `READY / RX: / LOG: / ERR:` up.

## Deploy (MicroPython)

```bash
# from the Pi the Pico A is attached to (e.g. /dev/ttyACM0):
mpremote connect /dev/ttyACM0 fs cp *.py :
mpremote connect /dev/ttyACM0 reset
```
The bridge driver (`hub.py` on the Pi) holds the serial port — **stop it before
running `mpremote`**, then restart it after.

## Gotchas

- SX1278 SPI ops need the `time.sleep_us(50)` delays in `lora.py` — removing them
  breaks reads silently.
- MicroPython `Timer` objects must be held on a module-level reference or GC frees
  them mid-countdown.
- GPS broadcasts are intentionally kept **out** of the chat history buffer (they’d
  flood it); only `CHAT:` reaches the OLED scroll.

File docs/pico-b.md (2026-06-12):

# Pico B — battery GPS tracker (reference node)

A standalone, battery-powered LoRa GPS tracker. It runs from a power bank with no
host attached, generates GPS broadcasts, detects and stores trips, and syncs them
to the hub when in range. It is the **behavioural reference** the ESP32-C3 port
mirrors — proven, in-production code.

| | |
|---|---|
| **Folder** | [../PicoB/](../PicoB/) |
| **MCU** | Raspberry Pi Pico (RP2040) |
| **Runtime** | MicroPython |
| **Radio / GPS** | SX1278 · NEO-7M |
| **Pinout** | [hardware.md → Pico B](hardware.md#pico-b--battery-tracker-picobconfigpy) |

## What it does

- **GPS cadence by movement class** with hysteresis: idle 60 s, walking 15 s,
  cycling 10 s, auto 10 s; walk→cycle at 8 km/h up / 6 down, cycle→auto at 27 up /
  23 down.
- **Trip detection** — IDLE↔MOVING with stop-detection timeouts per class
  (walking 120 s, cycling 60 s, auto 300 s stationary). Final classification is
  the peak sustained speed over any 5-minute window.
- **On-flash trip log** — per-trip `.gps` + `.json`, buffered writes
  (`FLUSH_EVERY`), `in_progress.txt` for power-cycle resume, `sync_state.json`
  for per-trip UNSENT/SENT/CONFIRMED.
- **Store-and-forward sync** — `SYNC:` on boot/after-trip/retry, answers the Pi’s
  `Q*` queries, marks CONFIRMED on `ACK`.
- **Presence** — `DEVICE:` heartbeat every 60 s; keeps an in-RAM roster of peers.
- **Resilience** — stale `in_progress` trips are auto-closed on boot; a watchdog
  force-closes a trip if GPS is lost mid-journey.

## Source layout ([../PicoB/](../PicoB/))

| File | Role |
|---|---|
| `runtime.py` | device main loop (radio + AES + GPS + tracker + sync + chat + presence) |
| `trip_tracker.py` | IDLE↔MOVING state machine |
| `trip_storage.py` | per-trip `.gps`/`.json` flash storage + sync state |
| `sync_codec.py` / `sync_manager.py` | RPTS codec + sync logic (mirror of the Pi side) |
| `gps_module.py` / `sx127x.py` | NMEA + radio drivers |
| `config.py` | device id, air params, AES key, pin map, cadences, thresholds |

## Deploy (MicroPython)

```bash
mpremote connect <PORT> fs cp *.py :
mpremote connect <PORT> reset
```
`DEVICE_ID` is read from `device_id.txt` on flash (renameable over LoRa via the
`DEVICE:` protocol); `DEVICE_HWID` comes from `machine.unique_id()`.

## Why it’s the reference

This node is kept stable on purpose: it’s the known-good implementation of the
trip-detection thresholds, sync state machine and file formats. When porting to
new hardware (as the ESP32-C3 does), Pico B’s behaviour is the spec — not a
refactor target.

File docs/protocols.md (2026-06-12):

# Communication protocols

Every layer of the link, from the LoRa PHY up to the application messages.

- [Radio (PHY)](#radio-phy)
- [Encryption](#encryption)
- [Pi ⇄ Pico A USB serial](#pi--pico-a-usb-serial)
- [Application messages (over LoRa)](#application-messages-over-lora)
- [Trip sync (store-and-forward)](#trip-sync-store-and-forward)
- [RPTS delta codec](#rpts-delta-codec)
- [Device identity & presence](#device-identity--presence)

---

## Radio (PHY)

All nodes use the **Semtech SX1276/78** (Ai-Thinker Ra-01 module) configured
identically — any mismatch and packets simply won’t decode:

| Parameter | Value |
|---|---|
| Carrier | **434.0 MHz** |
| Spreading factor | **SF9** |
| Bandwidth | **125 kHz** |
| Coding rate | **4/5** |
| Sync word | **0x34** |
| Preamble | **8** |
| CRC | **on** |
| TX power | **+20 dBm** (PA_BOOST) |

This is **raw LoRa, not LoRaWAN** — a private protocol with no network server,
no join procedure and no airtime duty-cycle middleware. You own the whole stack.

## Encryption

Application-layer **AES-128-ECB** with **PKCS#7** padding. The 16-byte key is
identical on every node (demo value `LoRaMeshDemoKey1` on this branch — change
it, see [../SECURITY.md](../SECURITY.md)). Plaintext is the tagged ASCII payload;
ciphertext must be **≤ 250 B** to fit one LoRa frame, so the chat body is capped
and trip data is fragmented (see below).

> ECB is used for simplicity/interoperability across three crypto libraries
> (mbedTLS on ESP32, `cryptolib` on MicroPython, `pycryptodome`/stdlib on the
> Pi). For production, prefer an authenticated mode (e.g. AES-GCM) + per-message
> nonce — noted in [../SECURITY.md](../SECURITY.md).

## Pi ⇄ Pico A USB serial

Pico A is a transparent modem for the Pi. Plaintext crosses USB; Pico A does the
AES on the radio side.

| Pi → Pico A | Meaning |
|---|---|
| `TX:<plaintext>` | encrypt + transmit over LoRa |
| `PING` | liveness check → `PONG` |
| `RESET` | re-init the radio → `READY` |
| `TIME:<iso>` | set the DS1302 RTC |

| Pico A → Pi | Meaning |
|---|---|
| `READY` | bridge up / radio re-armed |
| `RX:<text>\|<rssi>\|<snr>` | a decrypted LoRa packet + link quality |
| `LOG:<note>` / `ERR:<reason>` | diagnostics |

## Application messages (over LoRa)

Every payload begins with an **uppercase tag + `:`**. Untagged packets are logged
but never routed to chat.

| Tag | Direction | Payload | Purpose |
|---|---|---|---|
| `GPS:` | tracker → all | `{"hwid","lat","lon","ts"}` | live position dot |
| `TRIPSTART:` | tracker → hub | `{"device","hwid","id","ts","lat","lon"}` | trip began |
| `TRIPEND:` | tracker → hub | `{...,"km","dur","type","avg","max",...}` | trip finished |
| `CHAT:` | any → any | `CHAT:<sender>:<body>` | user message (body ≤ ~204 B) |
| `DEVICE:` | any → all / Pi→device | `{"id":<hwid>,"name":<name>}` | announce · heartbeat · rename |
| `WHO?` | Pi → all | — | presence probe; everyone re-announces `DEVICE:` |
| `QPOS:<target>` | Pi → device | — | on-demand position; target replies with `GPS:` |
| `SYNC:` / `Q*:` / `R*:` / `ACK:` | trip sync | see below | store-and-forward transfer |

Identity is carried by the **permanent hardware id (`hwid`)** — RP2040
`unique_id` (16 hex chars) or ESP32 chip MAC (12 hex chars) — so a device can be
renamed without breaking session routing.

## Trip sync (store-and-forward)

The tracker buffers complete trips on flash and the **Pi pulls them** when the
device announces. The Pi drives every step, which makes the transfer robust to
the lossy radio link.

```
 tracker                              Pi (Hub_Server)
   │  SYNC:<hwid>                ───────►  (I have unsent trips)
   │  ◄───────  QTRIPS:<hwid>              (enumerate)
   │  RTRIPS:<hwid>:T123:88,T456:42 ─────► (ids + point counts)
   │  ◄───────  QTRIP:T123                 (want metadata)
   │  RTRIP:T123:{json}            ──────► (start/end/km/dur/type/avg/max)
   │  ◄───────  QPTS:T123:0:11            (want points 0..11)
   │  RPTS:T123:0:[[...]]          ──────► (a delta-encoded batch)
   │  ◄───────  QPTS:T123:11:11           (next window)
   │      ... until all N points received ...
   │  ◄───────  ACK:T123                   (stored — delete it)
   ▼  delete T123.gps/.json, mark CONFIRMED
```

Robustness properties:

- **Pi-driven cursor.** The Pi tracks `expected_from` and advances only by the
  number of points actually decoded — so a short/partial batch never skips data.
- **Duplicate/stale rejection.** An `RPTS` whose `from_idx` ≠ the expected cursor
  is dropped (prevents double-counting if a `QPTS` retry races a slow reply).
- **Empty-batch ≠ done.** An empty `RPTS` while points are still expected triggers
  retry, not a premature `ACK` (so a marginal-RSSI moment can’t truncate a trip).
- **Idempotent recovery.** If a device resets mid-trip, on next boot it rebuilds
  the trip’s end-metadata from the fixes already on flash, so it still syncs as a
  complete trip instead of an empty/blank one.
- **ACK = delete.** Only after every point is in the DB does the Pi `ACK`, and
  only then does the tracker free the flash.

## RPTS delta codec

To pack as many fixes as possible into one ≤250 B AES frame, `RPTS` payloads are
delta-encoded JSON. The first fix is absolute; the rest are integer deltas:

```
[[ts0, lat0, lon0, alt0, spd0],          # absolute
 [dts, dlat, dlon, dalt, dspd], ...]      # deltas
   dts  = ts  - prev_ts        (s)
   dlat = round((lat-prev)*1e5) (1e-5 deg)
   dlon = round((lon-prev)*1e5)
   dalt = round(alt-prev)       (m)
   dspd = round((spd-prev)*10)  (0.1 km/h)
```

The encoder packs fixes until the next one would exceed the byte budget, returns
how many it packed, and the Pi requests the remainder in the next `QPTS`. Decoder
reverses it to absolute `[ts,lat,lon,alt,spd]`. Implemented identically in
`sync_codec.py` (MicroPython / Pi) and `sync_codec.cpp` (ESP32).

## Device identity & presence

One `DEVICE:{"id":<hwid>,"name":<name>}` message does three jobs:

1. **Boot announce** — lets the hub discover a new device (and offer a rename).
2. **Heartbeat** — re-sent **every 60 s** by every node. The Pi treats an
   unchanged-name announce as a heartbeat: it upserts `devices(id, name,
   last_seen, last_rssi)`. A device is **online** if heard within **10 minutes**.
3. **Rename** — a `DEVICE:` addressed to a device’s own hwid with a *different*
   name is a rename request; the device persists it and reboots, and the new
   boot announce confirms it. Because identity is the immutable hwid, renames
   never disturb stored trips or routing.

**Signal strength.** The bridge forwards each announce with its RSSI; the hub
stores it as `last_rssi` and both web UIs render a `X/10` score
(`-120 dBm → 1/10`, `-50 dBm → 10/10`). Each tracker also keeps a local roster of
peers it hears directly, so even with no Pi present a node knows who’s alive.

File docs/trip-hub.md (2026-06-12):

# Raspberry Pi 5 gateway — Hub_Server + Trip Hub web app

The Pi is the gateway and the dashboard host. Two cooperating Python 3 services:

- **`Hub_Server`** — the LoRa-side router and trip-sync engine (talks to Pico A
  over USB serial). [../Hub_Server/](../Hub_Server/)
- **`Trip_Hub`** — the Flask web app: map, analytics, chat, presence.
  [../Trip_Hub/](../Trip_Hub/)

Both read/write one SQLite file (`trips.db`).

## Hub_Server — the router & sync engine

| File | Role |
|---|---|
| `hub.py` | main entry: owns `/dev/ttyACM*` (Pico A), reconnect loop, RX dispatch, device-presence ingest, console TX |
| `splitter.py` | routes incoming payloads (`GPS:` → log + POST; `TRIP*` → POST) |
| `sync_manager.py` | Pi-side trip-sync state machine (`QTRIPS/QTRIP/QPTS` out, `RTRIPS/RTRIP/RPTS` in, `ACK`) |
| `sync_codec.py` | RPTS delta codec (mirror of the device side) |
| `chat_db.py` | SQLite chat persistence + pending-TX queue |

RX classification order: `DEVICE:` → sync → `GPS:` → `TRIP*` → `CHAT:` → else
(log only). Only `CHAT:` reaches the chat store; `GPS:`/`TRIP*` go to their
pipelines; everything else is logged but never pollutes chat.

```bash
cd Hub_Server
python3 hub.py                                # auto-detect Pico A
python3 hub.py --server http://localhost:5000 # also POST GPS/trips to Trip_Hub
```

## Trip_Hub — the web app

Single-page Flask app + Leaflet. See [web-interfaces.md](web-interfaces.md) for a
screenshot walkthrough.

| File | Role |
|---|---|
| `trip_server.py` | Flask app, SQLite access, all `/api/*` routes |
| `index.html` | the whole UI (map, chat, stats, activity log) — no build step |
| `import_trips.py` | bulk-import `T*.gps`/`.json` dropped into `incoming/trips/` |

Selected API:

| Endpoint | Purpose |
|---|---|
| `GET /` | the dashboard |
| `GET /api/trips` | list trips |
| `GET /api/trip/<id>` | one trip + polyline |
| `POST /api/live_point` | ingest a live `GPS:` fix (from Hub_Server) |
| `POST /api/trip` / `/api/trip_event` | ingest a synced/finished trip |
| `GET /api/devices/presence` | device roster `{name,hwid,last_seen,rssi}` for the chat dots |
| `POST /api/devices/probe` | broadcast a `WHO?` presence probe |
| chat + journeys endpoints | message history, send, journey grouping |

```bash
cd Trip_Hub
python3 trip_server.py     # serves http://<pi-ip>:5000 (binds 0.0.0.0)
```

## Data store (`trips.db`)

`trips`, `trip_points`, `live_points`, `messages`, `devices`
(`id`/`name`/`last_seen`/`last_rssi`), `journeys`, `journey_trips`. Schema +
migrations are created on `trip_server.py` startup. See
[architecture.md → Persistence](architecture.md#persistence-sqlite-tripsdb).

## Running both (example: tmux)

```bash
tmux new-session -d -s hub_server -c .../Hub_Server "python3 hub.py --server http://localhost:5000"
tmux new-session -d -s trip_hub   -c .../Trip_Hub  "python3 trip_server.py"
```
`Hub_Server` POSTs to `Trip_Hub` over local HTTP, so start/restart them
independently — just make sure **both** are up (it’s easy to restart the router
and forget the web app on `:5000`).

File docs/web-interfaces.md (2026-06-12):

# Web interfaces

Two completely independent web UIs — one served from the Pi gateway, one served
from the ESP32 itself with no Pi required.

---

## Trip Hub dashboard (Pi 5, `http://<pi-ip>:5000`)

A single-page Flask + Leaflet app. Four tabs plus a persistent chat/presence
sidebar and a device-scoped header (profile filter + date range).

### Map & journeys
Trip polylines coloured per movement profile over an OpenStreetMap base, with
per-profile summary tiles and a clickable trip list. Live `GPS:` broadcasts show
as a moving “you are here” dot.

Trip Hub — map

### Chat + device presence
LoRa chat with the fleet, with per-message RSSI/SNR. The dots beside **Chat**
are live presence: coloured = online (heard within 10 min), grey = offline.
Hover a dot for `name - online X/10, last seen …` (the `X/10` is signal strength).

Trip Hub — chat & presence

### Speed analytics
**Speed Distribution** and **Speed Trend** tabs render histograms / daily trends
from per-fix speed samples, with summary tiles (trips, km, hours, km/trip).

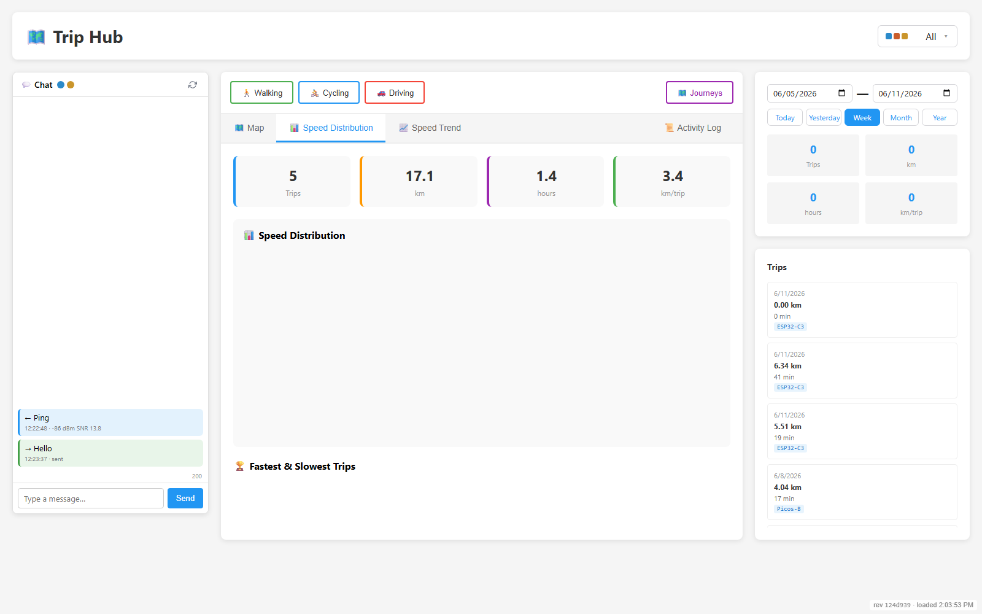
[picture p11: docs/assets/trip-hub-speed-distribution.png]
Trip Hub — speed distribution

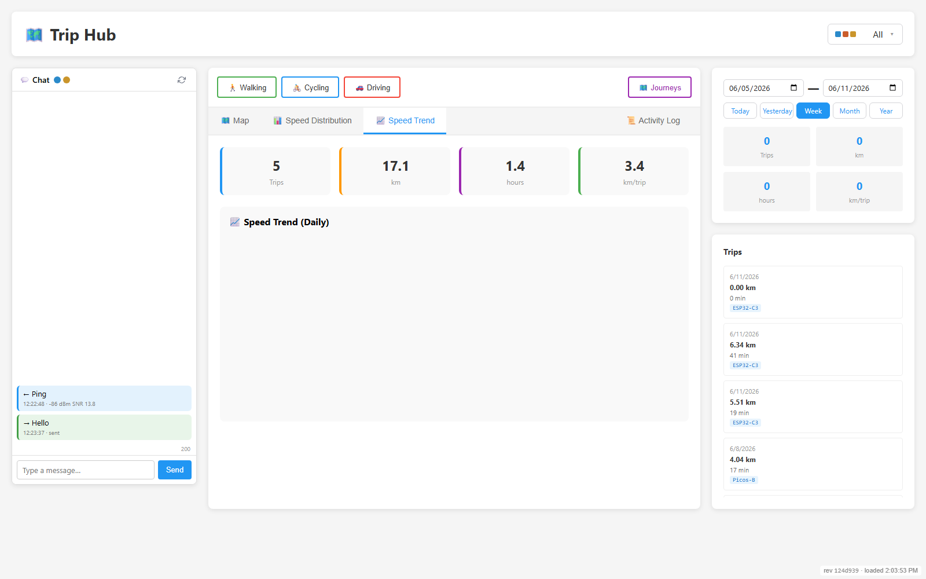
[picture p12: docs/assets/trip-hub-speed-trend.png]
Trip Hub — speed trend


### Activity log — live protocol traffic
A real-time view of decrypted radio traffic with RSSI/SNR — `DEVICE:` heartbeats,
the `QPTS`/`RPTS`/`ACK` trip-sync cycle, `QTRIPS`/`RTRIPS`, `SYNC`. The best window
into [the protocols](protocols.md).

Trip Hub — activity log

> Screenshots captured headlessly with Playwright against the live Pi
> (`_capture_shots.py`, kept out of the committed tree). Re-run any time to refresh.

---

## ESP32 on-device chat UI (`http://192.168.4.1`)

Hosted by the ESP32-C3’s own WiFi access point (SSID `LoraWan`) — **no Pi, no
internet**. Join the AP, the captive portal opens a sign-in, enter the device id,
and you’re chatting over LoRa with a live device-presence strip.

| 1 · Join `LoraWan` | 2 · Captive sign-in | 3 · Enter device id | 4 · Chat + presence |
|:---:|:---:|:---:|:---:|
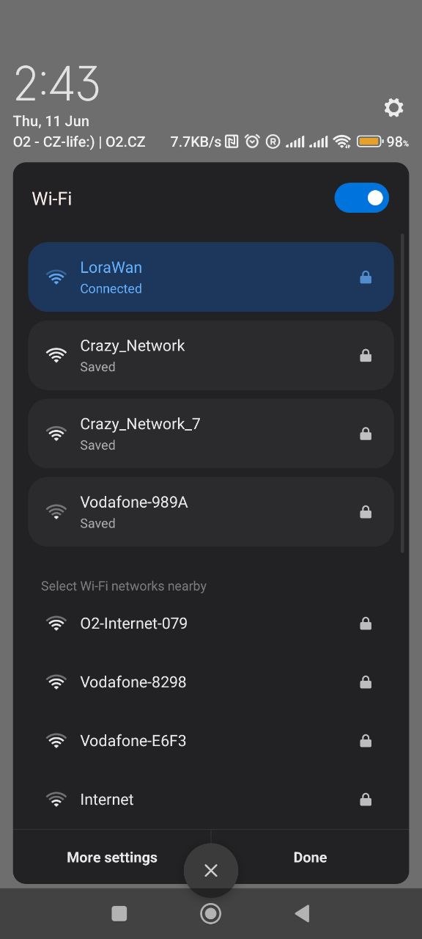
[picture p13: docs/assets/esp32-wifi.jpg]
Join the LoraWan softAP
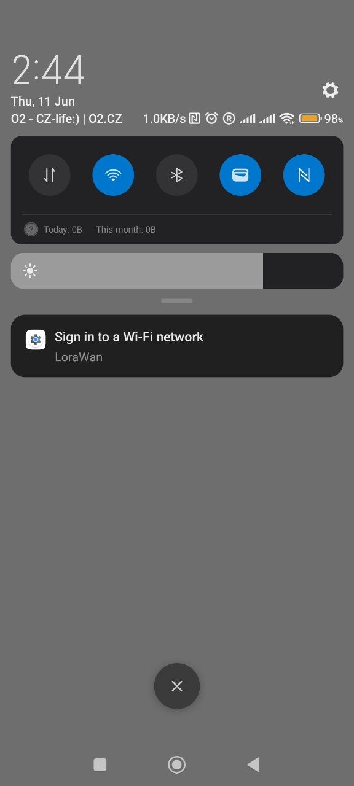
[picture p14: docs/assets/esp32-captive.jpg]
Captive-portal sign-in prompt
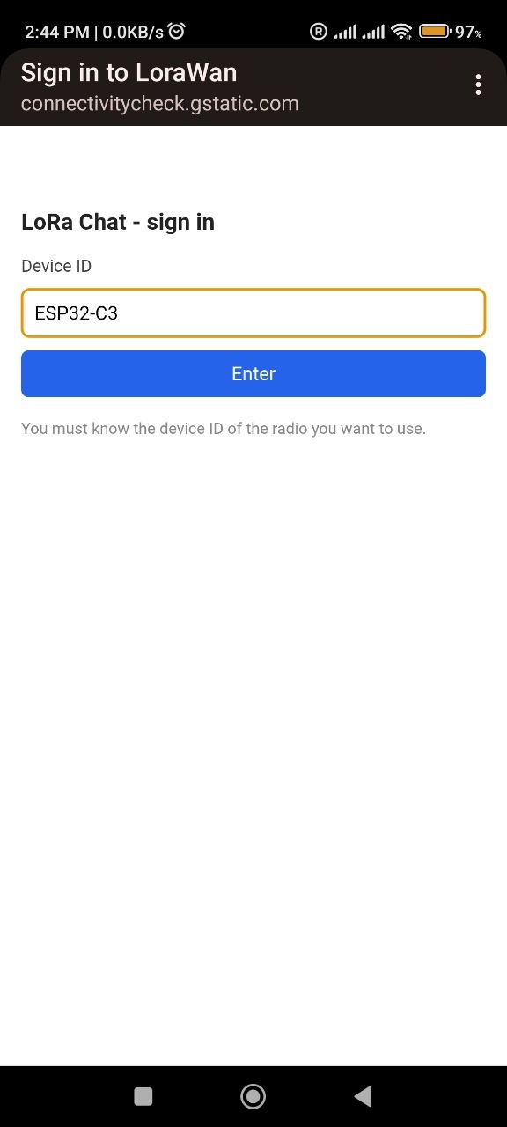
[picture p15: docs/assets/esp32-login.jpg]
LoRa Chat sign-in, device id ESP32-C3
|  |  |  | LoRa chat with device presence strip |

In the chat view, the **Devices** strip shows `ESP32-C3 (this)` and
`HubServer 7/10` — green = online, and the `X/10` is signal strength (here the
hub is a strong 7/10). Received messages carry their link quality
(`← HubServer:Hello · -79 dBm SNR 10.8`); the send box caps the body at 220 B.
All served straight off the ESP32, no Pi involved.

Endpoints backing this UI:
[esp32-c3.md → HTTP API](esp32-c3.md#http-api-behind-the-softap-auth-gated).

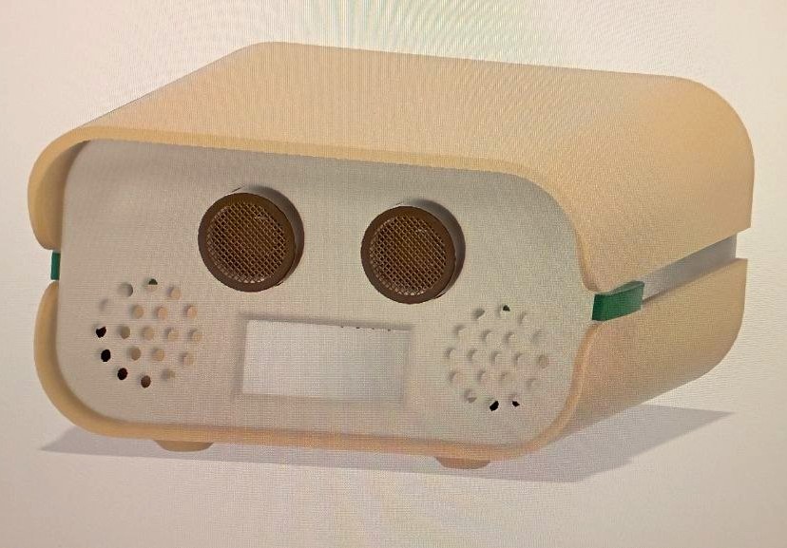
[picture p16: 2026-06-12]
docs/assets/case-pico-bridge-render.jpg

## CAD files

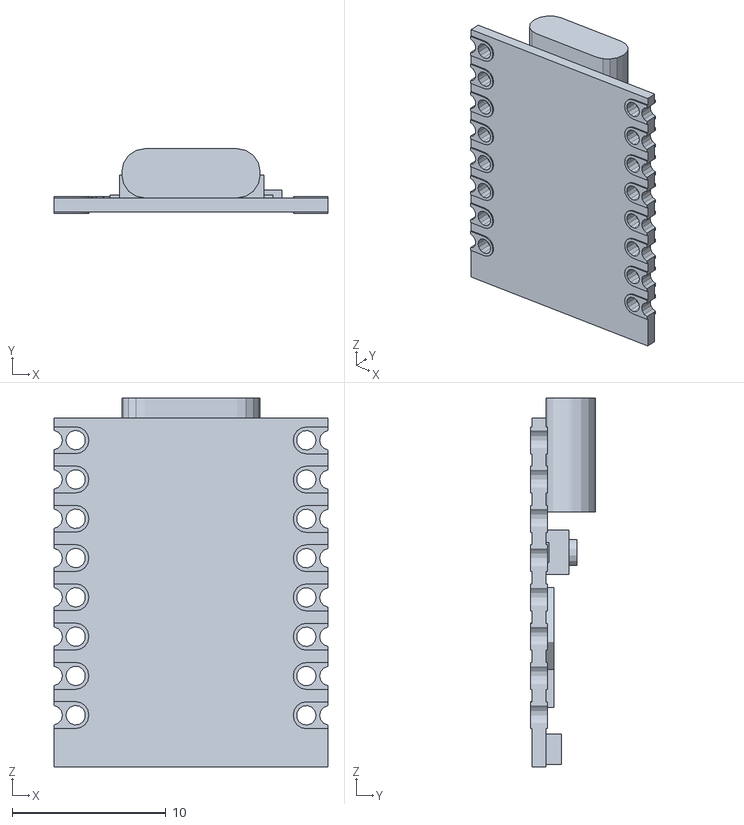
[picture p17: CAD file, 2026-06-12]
cad/esp32_case/esp32.stl
17.8 x 4.20 x 24.0

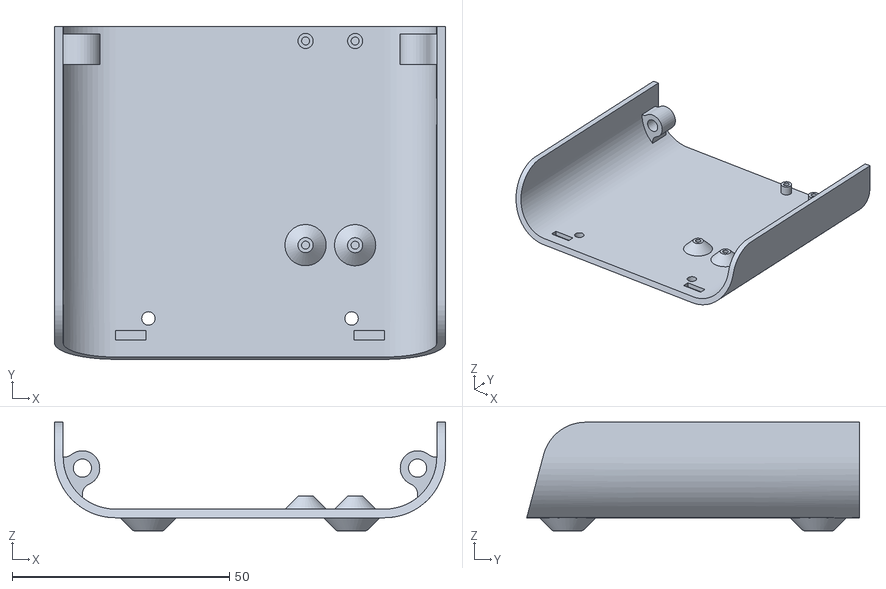
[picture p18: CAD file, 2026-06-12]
cad/pico_a_case/cover_bottom.stl
90.0 x 76.6 x 25.0

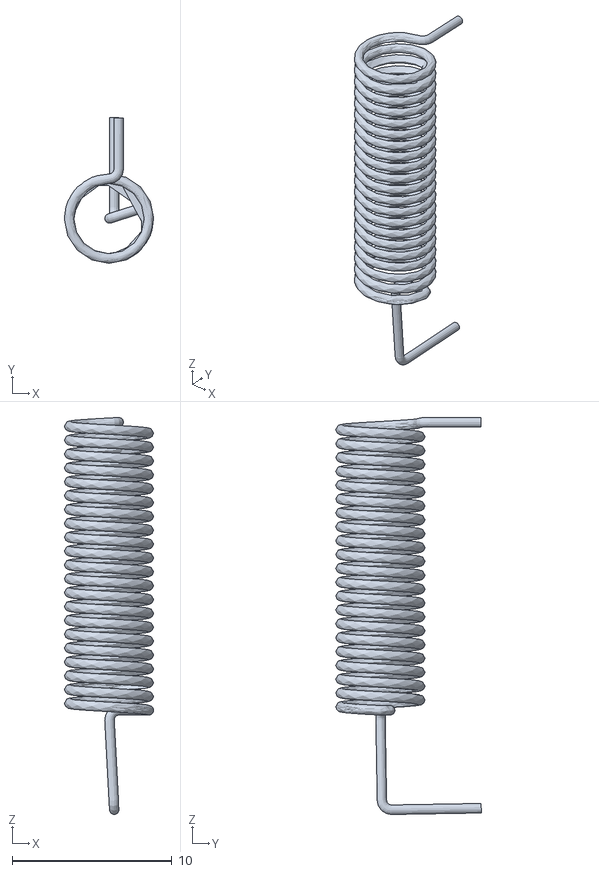
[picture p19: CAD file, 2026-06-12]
cad/esp32_case/lora_anthena.stl
5.60 x 9.12 x 24.9

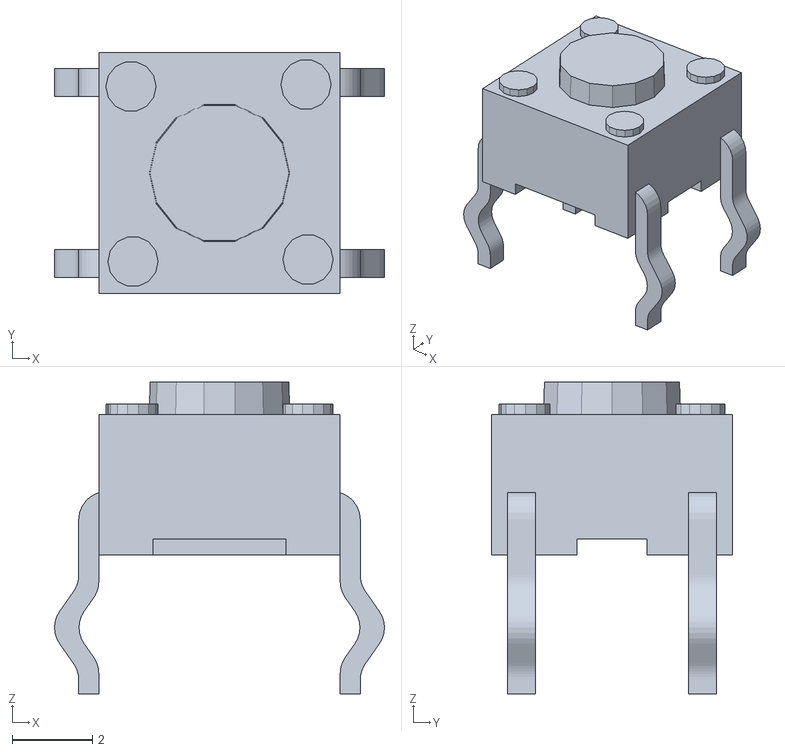
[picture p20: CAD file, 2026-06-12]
cad/pico_a_case/button_6X6X4.stl
8.20 x 6.00 x 7.75

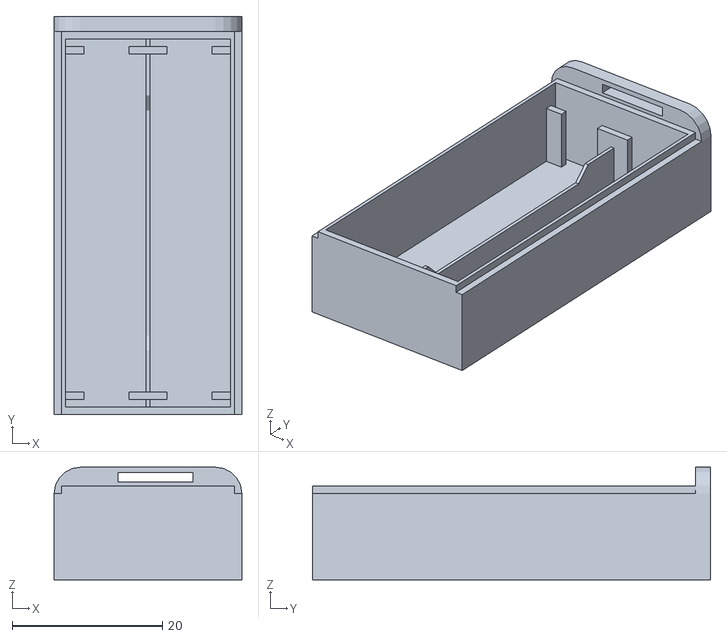
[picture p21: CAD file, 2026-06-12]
cad/esp32_case/Oximeter_3.stl
25.0 x 53.0 x 15.0

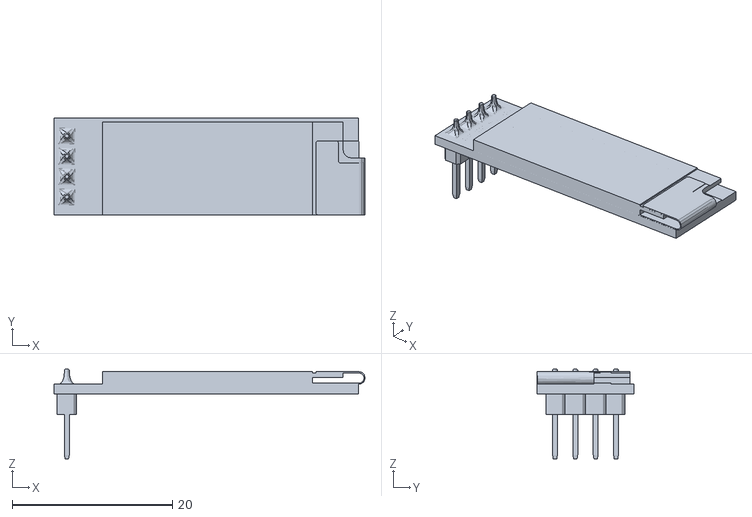
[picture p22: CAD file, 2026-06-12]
cad/pico_a_case/091_oled.stl
38.8 x 12.1 x 11.2

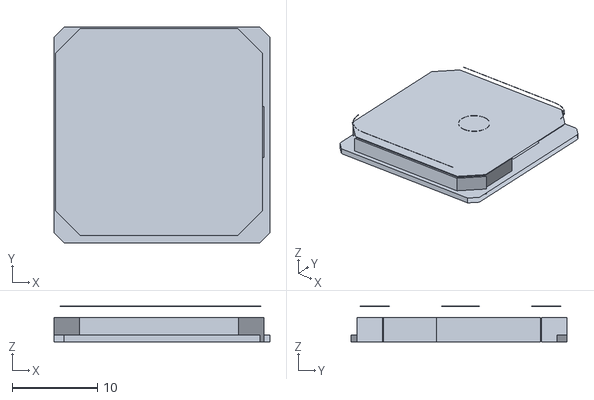
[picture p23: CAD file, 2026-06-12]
cad/esp32_case/GPS_ublox_anth.stl
25.4 x 25.4 x 4.18

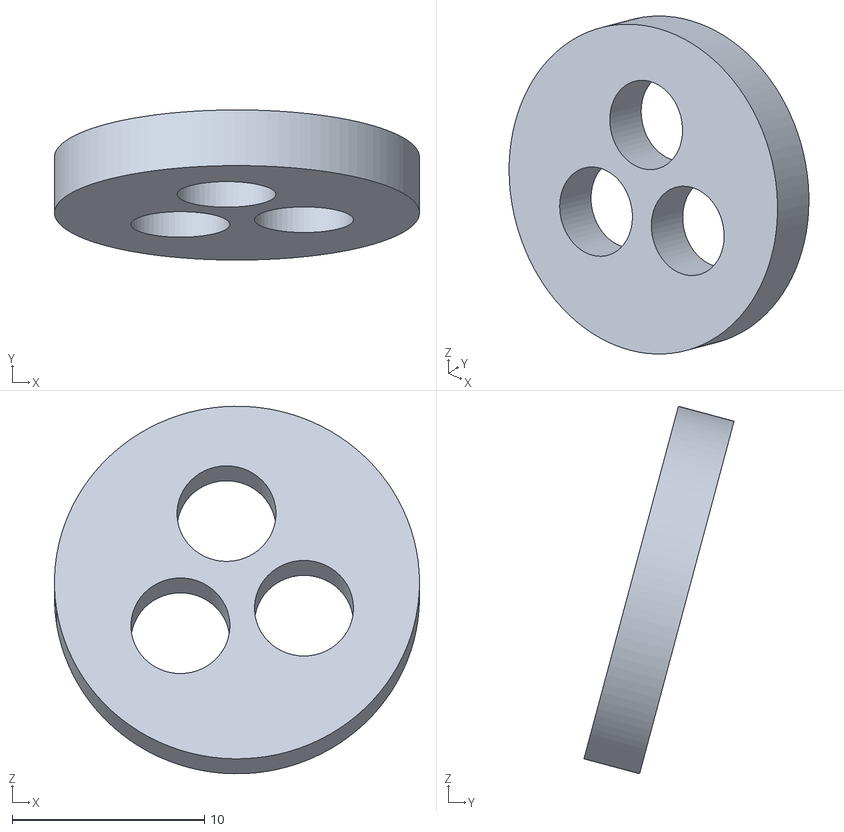
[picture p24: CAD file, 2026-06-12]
cad/pico_a_case/led_insert.stl
19.0 x 7.81 x 19.1

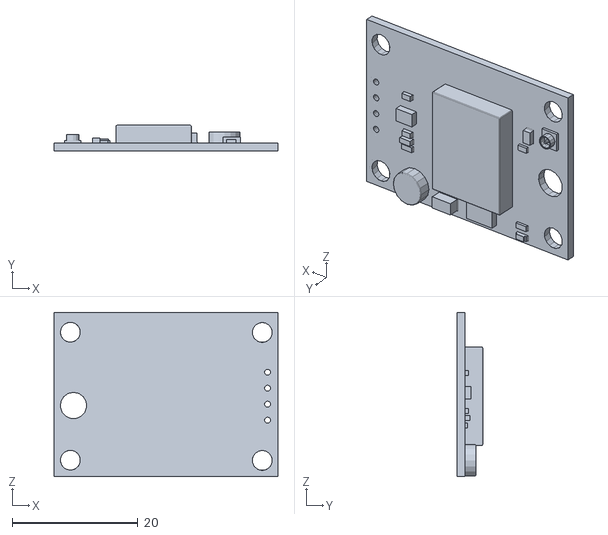
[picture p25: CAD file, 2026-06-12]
cad/esp32_case/GPS_ublox_board.stl
35.6 x 4.06 x 26.1

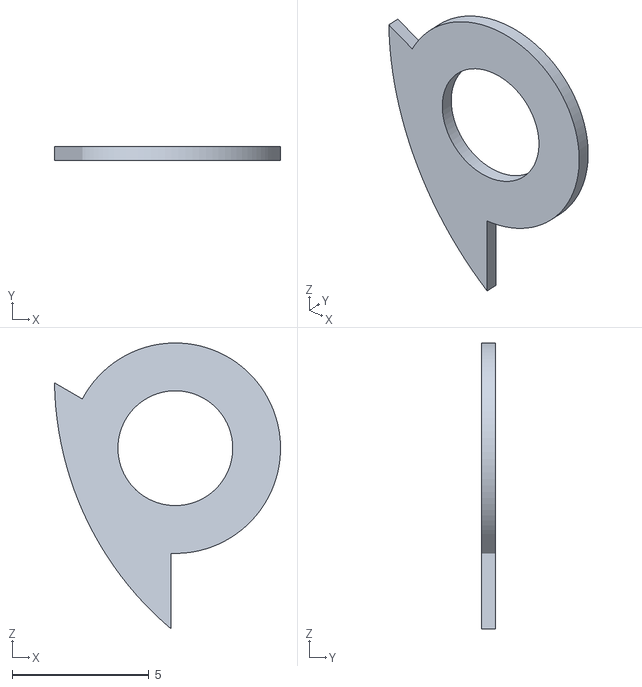
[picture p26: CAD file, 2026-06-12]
cad/pico_a_case/backplate_hole_print_insert.stl
8.27 x 0.5 x 10.5

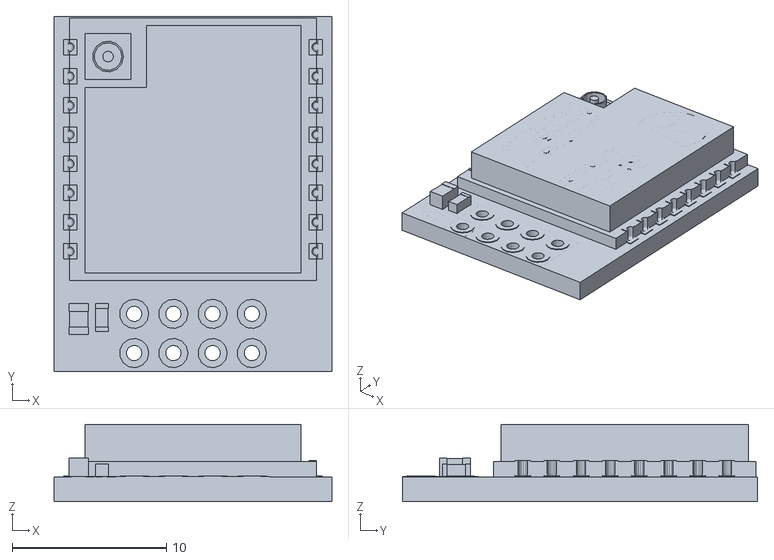
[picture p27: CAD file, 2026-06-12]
cad/esp32_case/LoRa-Ra-02.stl
18.0 x 23.0 x 5.00

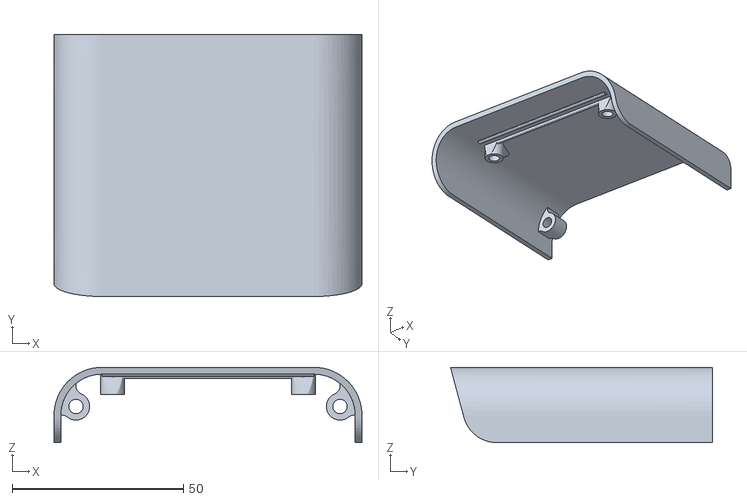
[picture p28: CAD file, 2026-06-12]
cad/pico_a_case/cover_top.stl
90.0 x 76.6 x 22.0

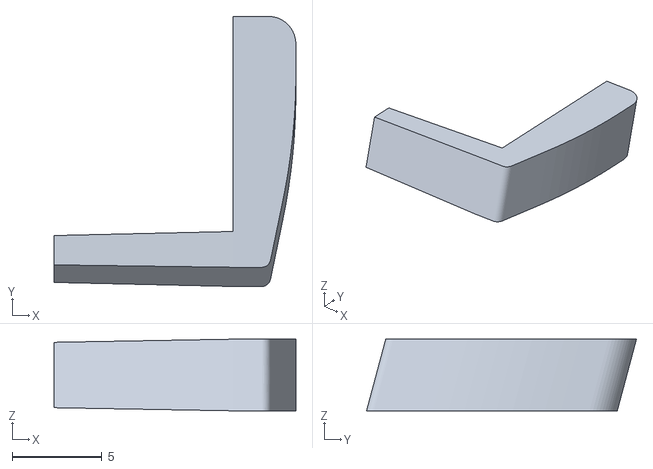
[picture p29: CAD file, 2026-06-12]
cad/pico_a_case/right_button.stl
13.5 x 15.1 x 4.00

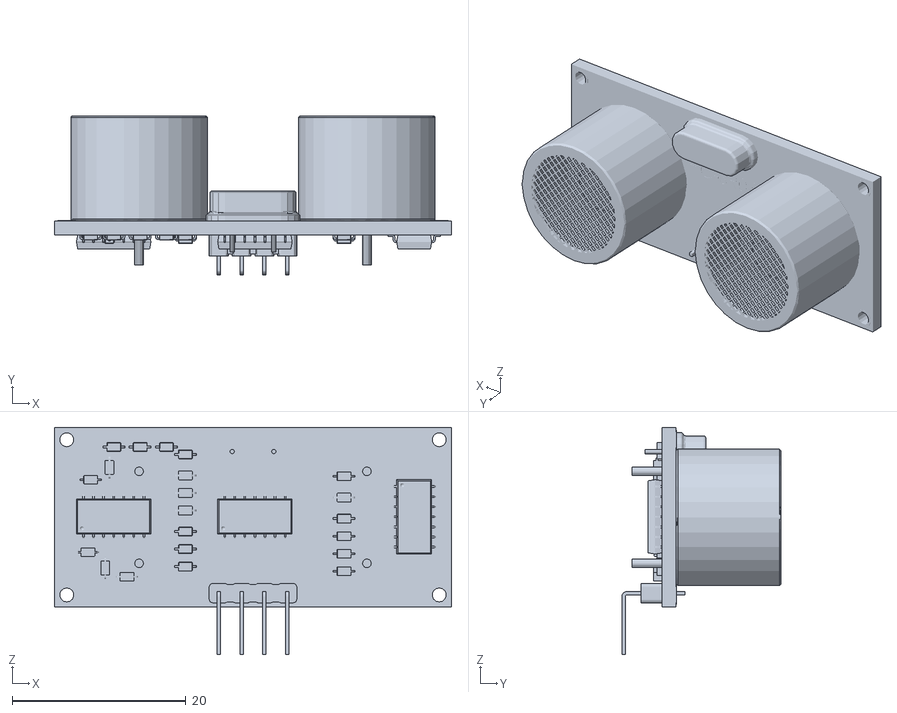
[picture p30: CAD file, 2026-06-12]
cad/pico_a_case/hc-sr04.stl
45.8 x 18.4 x 26.2

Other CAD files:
cad/pico_a_case/left_button.stl
cad/pico_a_case/5mm-led.stl
cad/pico_a_case/RTC DS1302.stl
cad/pico_a_case/Pi_Pico_2W_CAD_Reference.stl
cad/pico_a_case/buzzer.stl
cad/pico_a_case/dashboard.stl

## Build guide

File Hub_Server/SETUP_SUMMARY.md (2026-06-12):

# Hub_Server — Pi 5 setup

First-time setup for running [hub.py](hub.py) on a
Raspberry Pi 5 (Debian 12 Bookworm or newer).

## 1. Python deps

Stdlib does most of the work. The only external dep is `pyserial`:

```bash
sudo apt update
sudo apt install -y python3 python3-pip python3-serial
# OR via pip in a venv:
python3 -m venv .venv && source .venv/bin/activate
pip install pyserial
```

## 2. USB serial permissions

The Pico A enumerates as `/dev/ttyACM0` (or ACM1 if another USB-CDC
device is plugged in). Add the user to `dialout`:

```bash
sudo usermod -aG dialout $USER
# log out + back in for the group to apply
```

Verify Pico A is visible:

```bash
ls -l /dev/ttyACM*
# crw-rw---- 1 root dialout 166, 0 ... /dev/ttyACM0
```

## 3. Data directory

Default chat DB and live store live at `~/trip_data/`:

```bash
mkdir -p ~/trip_data
```

`hub.py --chat-db <path>` to override. Trip_Hub uses the same
directory for its SQLite + profiles.json — keep them on the same Pi
or symlink.

## 4. Run

```bash
cd ~/repo/esp32_projects/Hub_Server
python3 hub.py
```

Common flags:

| Flag | Effect |
|---|---|
| `--port /dev/ttyACM0` | skip auto-detect |
| `--log picoA_serial.log` | override raw serial log path |
| `--gps-log gps.log` | override GPS-only log path |
| `--server http://localhost:5000` | also POST `GPS:` payloads to Trip_Hub `/api/live_point` |
| `--chat-db /custom/path/trips.db` | override SQLite path |

Special prompts: type `PING`, `RESET`, or `QUIT` (or Ctrl-C) to exit.

## 5. Run on boot (optional)

Systemd unit at `/etc/systemd/system/hub-server.service`:

```ini
[Unit]
Description=Hub_Server LoRa client
After=multi-user.target

[Service]
Type=simple
User=pi
WorkingDirectory=/home/pi/repo/esp32_projects/Hub_Server
ExecStart=/usr/bin/python3 hub.py --server http://localhost:5000
Restart=on-failure
RestartSec=5

[Install]
WantedBy=multi-user.target
```

```bash
sudo systemctl daemon-reload
sudo systemctl enable --now hub-server.service
journalctl -u hub-server -f
```

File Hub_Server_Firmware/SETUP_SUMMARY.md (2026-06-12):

# Pico LoRa GPS Tracker - Complete Setup & Debug Summary

## PROJECT OVERVIEW
**Goal:** Two Pico RP2040 boards with Ra-01 SX1278 LoRa modules communicating on 433 MHz
**Status:** ✅ WORKING - Both TX and RX confirmed operational
**Total Debug Time:** 2 days (SPI communication was the main blocker)

---

## HARDWARE

### Pico RP2040 Specs
- Microcontroller: RP2040
- SPI0: GPIO2 (SCK), GPIO3 (MOSI), GPIO4 (MISO)
- Reset capability via GPIO22
- Built-in LED: GPIO25

### Ra-01 LoRa Module Specs
- IC: SX1278 (supports FSK, GFSK, LoRa modes)
- Frequency: 433 MHz (range 420-450 MHz)
- SPI: Half-duplex SPI communication
- Power: 3.3V, ~120mA TX, ~10mA RX
- Pin Pitch: 2.0 mm

---

## WIRING - Pico to Ra-01 LoRa Module

### Physical Pin Labels (Ra-01 Breakout v4.0)
```
Left Side       Right Side
MISO            100 (DIO0)
SCK             MOSI
RST             NSS
GND             3V3
```

### Pico Connection Map

| Ra-01 Pin | Ra-01 Label | → | Pico Physical | Pico GPIO | Function |
|---|---|---|---|---|---|
| 1 | MISO | → | 6 | GPIO4 | SPI Data In |
| 2 | SCK | → | 4 | GPIO2 | SPI Clock |
| 3 | RST | → | 29 | GPIO22 | Reset |
| 4 | GND | → | 3 | GND | Ground |
| 5 | DIO0/100 | → | 31 | GPIO26 | Interrupt (optional) |
| 6 | MOSI | → | 5 | GPIO3 | SPI Data Out |
| 7 | NSS | → | 7 | GPIO5 | Chip Select |
| 8 | 3V3 | → | 36 | 3V3 | Power |

**CRITICAL:** Check physical pin numbers against Pico pinout diagram!

---

## CRITICAL DISCOVERIES (2-Day Debug Log)

### Issue #1: FSK vs LoRa Mode ❌→✅
**Problem:** Code was using FSK register map, but Ra-01 defaults to LoRa
**Solution:** Set bit 7 (0x80) of REG_OP_MODE to enable LoRa mode
```python
write_reg(0x01, 0x81)  # MODE_STANDBY | LORA_MODE (0x80 | 0x01)
```

### Issue #2: Pico SPI Read Pattern ❌→✅
**Problem:** Standard `write()` + `read()` pattern returned 0x00
**Solution:** Use `write_readinto()` with 2-byte buffer
```python
# WRONG:
cs.off()
spi.write(bytes([0x42]))
cs.on()
data = spi.read(1)  # Returns 0x00 ❌

# CORRECT:
cs.off()
buf = bytearray(2)
spi.write_readinto(bytes([0x42, 0x00]), buf)
cs.on()
return buf[1]  # buf[1] has actual data ✅
```

### Issue #3: Pi 5 LoRa RX (Separate Issue)
**Problem:** Pi 5 received empty FIFO despite proper configuration
**Solution:** Pi 5 LoRa RX was never fully debugged (Pico solution used instead)
**Key Finding:** Pi 5 requires `xfer2()` atomic transactions (not available on Pico)

---

## REGISTER MAP (LoRa Mode)

| Register | Address | Purpose | Value |
|---|---|---|---|
| OpMode | 0x01 | Operating mode | 0x81 (LoRa+Standby) |
| FRF_MSB | 0x06 | Frequency MSB | 0x6C (433 MHz) |
| FRF_MID | 0x07 | Frequency MID | 0x80 |
| FRF_LSB | 0x08 | Frequency LSB | 0x00 |
| PA_Config | 0x09 | Power amp | 0xFF (20dBm) |
| LNA | 0x0C | Low noise amp | 0x23 (max gain) |
| FIFO_Ptr | 0x0D | FIFO address | 0x00 (reset) |
| IRQ_Flags | 0x12 | Interrupt flags | 0xFF (clear all) |
| RX_NB_Bytes | 0x13 | Bytes received | - |
| ModemCfg1 | 0x1D | BW & CR | 0x72 (125kHz, 4/5) |
| ModemCfg2 | 0x1E | SF & CRC | 0x74 (SF7, CRC on) |
| ModemCfg3 | 0x26 | AGC | 0x04 (auto) |
| PreambleMSB | 0x20 | Preamble | 0x00 |
| PreAmbleLSB | 0x21 | Preamble | 0x08 (8 symbols) |
| SyncWord | 0x39 | LoRa sync | 0x34 (public) |
| Version | 0x42 | Chip version | 0x12 (SX1278) |

### LoRa Configuration Used
- **Spreading Factor:** 7
- **Bandwidth:** 125 kHz
- **Coding Rate:** 4/5
- **Sync Word:** 0x34 (LoRa public)
- **Preamble:** 8 symbols
- **CRC:** Enabled

---

## WORKING CODE

### Pico #1 - TX (pico1_lora_tx_fixed_final.py)
```python
def read_reg(self, reg):
    """CRITICAL: Use write_readinto, return buf[1]"""
    self.cs.off()
    buf = bytearray(2)
    self.spi.write_readinto(bytes([reg, 0x00]), buf)
    self.cs.on()
    time.sleep(0.01)
    return buf[1]  # ← KEY: data is in buf[1]

def write_reg(self, reg, value):
    self.cs.off()
    self.spi.write(bytes([reg | 0x80, value]))
    self.cs.on()
    time.sleep(0.01)
```

### Pico #2 - RX (pico2_lora_rx_fixed_final.py)
Same read/write pattern as TX, but set to RX_CONTINUOUS mode (0x05)

### Key Settings Both Sides Must Match:
- Frequency: 433 MHz (0x6C8000)
- ModemCfg1: 0x72 (BW 125k, CR 4/5)
- ModemCfg2: 0x74 (SF 7, CRC on)
- SyncWord: 0x34

---

## TESTING & VERIFICATION

### Step 1: SPI Test
```python
from machine import SPI, Pin
spi = SPI(0, baudrate=10000000, sck=Pin(2), mosi=Pin(3), miso=Pin(4))
cs = Pin(5, Pin.OUT)
cs.off()
buf = bytearray(2)
spi.write_readinto(bytes([0x42, 0x00]), buf)  # Read version
cs.on()
print(f"Version: 0x{buf[1]:02x}")  # Should be 0x12
```

### Step 2: Full Diagnostic
Run `pico2_diagnostic_fixed.py` - confirms all registers writable

### Step 3: Communication Test
- Upload TX to Pico #1
- Upload RX to Pico #2
- Place close (< 1 meter)
- Should see: `[RX #1] ✅ Received: 'HELLO_001'`

### Success Indicators
✅ LED on Pico #2 lights up = message received
✅ Message counter increments = both sides working
✅ Multiple messages received = stable link

---

## TIMING DELAYS (CRITICAL)

All SPI operations must include delays:
```python
time.sleep(0.01)  # After write_reg
time.sleep(0.01)  # After read_reg
time.sleep(0.1)   # After mode change
time.sleep(0.5)   # After reset
```

Without delays, SPI reads return stale data!

---

## COMMON MISTAKES TO AVOID

❌ Using FSK register map (0x02, 0x03 for bitrate) - use LoRa mode (0x1D, 0x1E, 0x26)
❌ Using `write()` + `read()` separately - use `write_readinto()` with buf[1]
❌ Forgetting the 0x80 bit for LoRa mode
❌ Different frequency/BW/SF/CR on TX vs RX
❌ Not clearing IRQ flags after RX
❌ No time.sleep() between SPI operations
❌ Wrong FIFO pointer reset (must be 0x00)

---

## FILES LOCATION

All working code in `/mnt/user-data/outputs/`:
- `pico1_lora_tx_fixed_final.py` - Transmitter code
- `pico2_lora_rx_fixed_final.py` - Receiver code  
- `pico2_diagnostic_fixed.py` - Full register diagnostic
- `pico2_spi_simple_test.py` - SPI method comparison

---

## FOR NEXT SESSION

1. **Upload code** from outputs folder to Pico boards
2. **Check wiring** against pin table above
3. **Run SPI test** to verify communication
4. **Run diagnostic** if TX/RX not working
5. **Verify frequency match** (both 433 MHz)
6. **Check LED** blinks on RX (listening) / solid (message)

**Expected output:**
```
[RX #1] ✅ Received: 'HELLO_001'
[RX #2] ✅ Received: 'HELLO_002'
...
```

---

## NEXT IMPROVEMENTS

- [ ] Add GPS data to messages
- [ ] Switch to binary protocol (smaller messages)
- [ ] Add error handling/retries
- [ ] Implement sleep modes for battery
- [ ] Test range at distance
- [ ] Add timestamp to messages
- [ ] Implement ACK/NACK
- [ ] Add channel hopping

---

## REFERENCE LINKS

- SX1278 Datasheet: https://cdn-shop.adafruit.com/product-files/3179/sx1276_77_78_79.pdf
- Pico Pinout: https://datasheets.raspberrypi.com/pico/pico-datasheet.pdf
- Ra-01 Manual: (see uploaded PDF)

---

**Last Updated:** 2 days of debugging complete ✅
**Status:** Both Pico boards communicating on LoRa 433 MHz
**Next Step:** Integrate GPS and test real-world range

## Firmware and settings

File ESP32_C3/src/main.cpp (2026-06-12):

#include <Arduino.h>
#include <ctype.h>
#include <string.h>
#include <stdio.h>
#include <LittleFS.h>
#include "config.h"
#include "lora_radio.h"
#include "gps.h"
#include "net.h"
#include "web_server.h"
#include "chat_log.h"
#include "trip_storage.h"
#include "sync_manager.h"
#include "trip_tracker.h"
#include "presence.h"

// Runtime device id (declared extern in config.h). Initialised to the
// compile-time default here; overridden from /device_id.txt on boot.
char g_deviceId[16] = DEVICE_ID;
static const char* DEVICE_ID_FILE = "/device_id.txt";

// Permanent hardware id, hex of the 6-byte chip MAC. Burned at the
// factory; survives any flash erase. Pi 5 addresses rename commands to
// this so the (renameable) name and the (immutable) device identity
// stay separate on the wire. Exported via extern in config.h so
// sync_manager etc. can read it.
char g_deviceHwid[16] = {0};
static void computeHwid() {
  uint64_t mac = ESP.getEfuseMac();          // 48-bit chip id, low 6 bytes
  snprintf(g_deviceHwid, sizeof(g_deviceHwid),
           "%012llx", (unsigned long long)mac);
}

static bool g_radioOk = false;

// ---- Device-id persistence -------------------------------------------------
static bool isValidDeviceId(const char* s, size_t n) {
  if (n == 0 || n >= 16) return false;
  for (size_t i = 0; i < n; i++) {
    char c = s[i];
    if (!(isalnum((unsigned char)c) || c == '_' || c == '-')) return false;
  }
  return true;
}

static void loadDeviceId() {
  if (!LittleFS.begin(true)) return;   // also called by Chat.begin; idempotent
  if (!LittleFS.exists(DEVICE_ID_FILE)) {
    Serial.printf("device_id=%s (compile-time default)\n", g_deviceId);
    return;
  }
  File f = LittleFS.open(DEVICE_ID_FILE, "r");
  if (!f) { Serial.println("device_id: open failed"); return; }
  char buf[24] = {0};
  size_t n = f.read((uint8_t*)buf, sizeof(buf) - 1);
  f.close();
  // Trim trailing whitespace / newlines
  while (n > 0 && (buf[n-1] == '\n' || buf[n-1] == '\r' ||
                   buf[n-1] == ' '  || buf[n-1] == '\t')) {
    buf[--n] = '\0';
  }
  if (isValidDeviceId(buf, n)) {
    memcpy(g_deviceId, buf, n);
    g_deviceId[n] = '\0';
    Serial.printf("device_id=%s (loaded from flash)\n", g_deviceId);
  } else {
    Serial.printf("device_id file invalid, using default %s\n", g_deviceId);
  }
}

// Persist a new device id and reboot. Used by handleRenameMessage().
static bool persistDeviceIdAndRestart(const char* newId) {
  File f = LittleFS.open(DEVICE_ID_FILE, "w");
  if (!f) return false;
  f.print(newId);
  f.close();
  Serial.printf("[RENAME] persisted %s, rebooting\n", newId);
  delay(500);          // let any in-flight serial / LoRa drain
  ESP.restart();
  return true;         // unreachable
}

// Extract a "key":"value" string from a JSON-ish blob into out. We
// control both ends of the wire so a strstr-based parser is enough — no
// nesting, no escapes, all values are quoted strings.
static bool jsonGetStr(const char* blob, const char* key,
                       char* out, size_t outSize) {
  char pattern[24];
  snprintf(pattern, sizeof(pattern), "\"%s\":\"", key);
  const char* p = strstr(blob, pattern);
  if (!p) return false;
  p += strlen(pattern);
  const char* end = strchr(p, '"');
  if (!end) return false;
  size_t n = (size_t)(end - p);
  if (n >= outSize) n = outSize - 1;
  memcpy(out, p, n);
  out[n] = '\0';
  return true;
}

// Handle DEVICE:<json> umbrella for device-management.
// Wire grammar — every payload carries BOTH fields:
//   id   = permanent hardware id (hex)             - immutable
//   name = renameable label loaded from /device_id.txt
// DEVICE:{"id":"<hwid>","name":"<current_or_new_name>"}
//
// Direction is implicit:
//   announce (device->Pi):  id=mine, name=mine
//   rename   (Pi->device):  id=mine, name=<new>     (name != current)
//   ack post-reboot:        id=mine, name=<new>     (name now == current)
//
// A packet whose id matches OUR hwid AND whose name differs from
// g_deviceId is a rename request — persist + reboot. Other shapes
// (id not ours, or name == current) are silently consumed.
static bool handleDeviceMessage(const char* text, int16_t rssi) {
  if (strncmp(text, "DEVICE:", 7) != 0) return false;
  const char* body = text + 7;

  char hwid[24] = {0}, name[16] = {0};
  if (!jsonGetStr(body, "id",   hwid, sizeof(hwid))) return true;
  if (!jsonGetStr(body, "name", name, sizeof(name))) return true;

  // Every DEVICE: announce doubles as a liveness heartbeat. Record the
  // peer before the rename checks below (which only concern our own hwid).
  if (strcmp(hwid, g_deviceHwid) != 0) {
    Presence.noteSeen(hwid, name, rssi, millis());
  }

  if (strcmp(hwid, g_deviceHwid) != 0)        return true;  // not us
  if (strcmp(name, g_deviceId)   == 0)        return true;  // echo / no-op
  if (!isValidDeviceId(name, strlen(name)))   return true;

  Serial.printf("[DEVICE] rename %s -> %s (hwid=%s)\n",
                g_deviceId, name, g_deviceHwid);
  persistDeviceIdAndRestart(name);   // does not return
  return true;
}

// ----- Cadence-by-class with hysteresis (mirrors PicoB runtime.py) ------
static MoveClass g_class      = CLASS_IDLE;
static float     g_recentSpd[gps_cfg::SPEED_SMOOTH_N] = {0};
static size_t    g_recentIdx  = 0;
static size_t    g_recentN    = 0;

static float pushAndSmoothSpd(float spd) {
  g_recentSpd[g_recentIdx] = spd;
  g_recentIdx = (g_recentIdx + 1) % gps_cfg::SPEED_SMOOTH_N;
  if (g_recentN < gps_cfg::SPEED_SMOOTH_N) g_recentN++;
  float sum = 0;
  for (size_t i = 0; i < g_recentN; i++) sum += g_recentSpd[i];
  return sum / (float)g_recentN;
}

static MoveClass pickClass(float spd, MoveClass prev) {
  using namespace gps_cfg;
  if (prev == CLASS_WALKING) {
    if (spd >= WALK_TO_CYCLE_UP) {
      return (spd < CYCLE_TO_DRIVING_UP) ? CLASS_CYCLING : CLASS_DRIVING;
    }
    return CLASS_WALKING;
  }
  if (prev == CLASS_CYCLING) {
    if (spd >= CYCLE_TO_DRIVING_UP)   return CLASS_DRIVING;
    if (spd <  CYCLE_TO_WALK_DOWN) return CLASS_WALKING;
    return CLASS_CYCLING;
  }
  if (prev == CLASS_DRIVING) {
    if (spd < DRIVING_TO_CYCLE_DOWN) {
      return (spd < CYCLE_TO_WALK_DOWN) ? CLASS_WALKING : CLASS_CYCLING;
    }
    return CLASS_DRIVING;
  }
  // First call from IDLE: pick by static thresholds.
  if (spd >= CYCLE_TO_DRIVING_UP) return CLASS_DRIVING;
  if (spd >= WALK_TO_CYCLE_UP) return CLASS_CYCLING;
  return CLASS_WALKING;
}

static uint32_t intervalForClass(MoveClass c) {
  switch (c) {
    case CLASS_WALKING: return gps_cfg::WALKING_INTERVAL_MS;
    case CLASS_CYCLING: return gps_cfg::CYCLING_INTERVAL_MS;
    case CLASS_DRIVING:    return gps_cfg::DRIVING_INTERVAL_MS;
    default:            return gps_cfg::IDLE_INTERVAL_MS;
  }
}

// ----- On-demand position query (QPOS:<target>) -----
// Returns true if the wire-format matched (whether or not we replied),
// so the caller can short-circuit further dispatch. Target may be our
// hwid (new wire grammar) or our renameable name (legacy fallback).
static bool handleQposMessage(const char* text);

// ----- Broadcast presence probe (WHO?) -----
// Pi 5 sends a single WHO? to all devices; each replies with the same
// DEVICE: announce it emits on boot. Receiver-side ingest bumps
// devices.last_seen, which is what the chat presence dots read.
static bool handleWhoMessage(const char* text);

static void sendDeviceAnnounce() {
  if (!g_radioOk) return;
  char ann[64];
  snprintf(ann, sizeof(ann),
           "DEVICE:{\"id\":\"%s\",\"name\":\"%s\"}",
           g_deviceHwid, g_deviceId);
  Radio.sendEncrypted(ann);
}

// ----- LoRa-side broadcasts -----
// GPS: payload is intentionally minimal — identity + position + ts.
// The live map dot is the only consumer; altitude/speed live in the
// trip log (TRIPEND + RPTS sync data), not in periodic broadcasts.
// Saves ~40 B per packet (~150 ms airtime at SF9).
static void broadcastGps(const sync_codec::Fix& f) {
  if (!g_radioOk || Sync.sessionActive()) {
    if (Sync.sessionActive()) Serial.println("[GPS TX skipped: sync active]");
    return;
  }
  char body[120];
  int n = snprintf(body, sizeof(body),
    "GPS:{\"hwid\":\"%s\",\"lat\":%.6f,\"lon\":%.6f,\"ts\":%ld}",
    g_deviceHwid, f.lat, f.lon, (long)f.ts);
  if (n <= 0 || (size_t)n >= sizeof(body)) return;
  bool ok = Radio.sendEncrypted(body);
  Serial.printf("[GPS TX] %s (%s)\n", body, ok ? "OK" : "FAIL");
}

static bool handleQposMessage(const char* text) {
  if (strncmp(text, "QPOS:", 5) != 0) return false;
  const char* target = text + 5;
  while (*target == ' ') target++;
  if (strcmp(target, g_deviceHwid) != 0 && strcmp(target, g_deviceId) != 0) {
    return true;  // someone else's ping — consumed but not for us
  }
  sync_codec::Fix f;
  if (!Gps.latestFix(&f)) {
    Serial.println("[QPOS] no fix yet, ignoring");
    return true;
  }
  broadcastGps(f);
  return true;
}

static bool handleWhoMessage(const char* text) {
  if (strncmp(text, "WHO?", 4) != 0) return false;
  Serial.println("[WHO] re-announcing DEVICE");
  sendDeviceAnnounce();
  return true;
}

static void broadcastTripStart(const TripStart& s) {
  if (!g_radioOk) return;
  char body[220];
  int n = snprintf(body, sizeof(body),
    "TRIPSTART:{\"device\":\"%s\",\"hwid\":\"%s\",\"id\":\"%s\","
    "\"ts\":%ld,\"lat\":%.6f,\"lon\":%.6f}",
    g_deviceId, g_deviceHwid, s.id, (long)s.ts, s.lat, s.lon);
  if (n <= 0 || (size_t)n >= sizeof(body)) return;
  bool ok = Radio.sendEncrypted(body);
  Serial.printf("[TRIPSTART] %s (%s)\n", s.id, ok ? "OK" : "FAIL");
}

static void broadcastTripEnd(const TripEnd& e) {
  if (!g_radioOk) return;
  char body[260];
  int n = snprintf(body, sizeof(body),
    "TRIPEND:{\"device\":\"%s\",\"hwid\":\"%s\",\"id\":\"%s\","
    "\"sts\":%ld,\"ets\":%ld,"
    "\"slat\":%.6f,\"slon\":%.6f,\"elat\":%.6f,\"elon\":%.6f,"
    "\"km\":%.3f,\"dur\":%lu,\"type\":\"%s\","
    "\"avg\":%.2f,\"max\":%.2f}",
    g_deviceId, g_deviceHwid, e.id,
    (long)e.sts, (long)e.ets,
    e.slat, e.slon, e.elat, e.elon,
    e.km, (unsigned long)e.dur_s,
    moveClassName(e.type),
    e.avg_kmh, e.max_kmh);
  if (n <= 0 || (size_t)n >= sizeof(body)) return;
  bool ok = Radio.sendEncrypted(body);
  Serial.printf("[TRIPEND] %s type=%s km=%.3f (%s)\n",
                e.id, moveClassName(e.type), e.km, ok ? "OK" : "FAIL");
}

// ----- Persist a started/ended trip's meta -----
static void persistTripStart(const TripStart& s) {
  trip_storage::Meta meta = {};
  strncpy(meta.device, g_deviceId,   sizeof(meta.device) - 1);
  strncpy(meta.hwid,   g_deviceHwid, sizeof(meta.hwid)   - 1);
  strncpy(meta.id,     s.id,         sizeof(meta.id)     - 1);
  meta.sts  = s.ts;
  meta.slat = s.lat;
  meta.slon = s.lon;
  strncpy(meta.type, "unknown", sizeof(meta.type) - 1);
  trip_storage::writeMeta(s.id, meta);
  trip_storage::setInProgress(s.id);
}

static void persistTripEnd(const TripEnd& e) {
  trip_storage::Meta meta = {};
  strncpy(meta.device, g_deviceId,   sizeof(meta.device) - 1);
  strncpy(meta.hwid,   g_deviceHwid, sizeof(meta.hwid)   - 1);
  strncpy(meta.id,     e.id,         sizeof(meta.id)     - 1);
  meta.sts     = e.sts;
  meta.ets     = e.ets;
  meta.slat    = e.slat;
  meta.slon    = e.slon;
  meta.elat    = e.elat;
  meta.elon    = e.elon;
  meta.km      = e.km;
  meta.dur_s   = e.dur_s;
  strncpy(meta.type, moveClassName(e.type), sizeof(meta.type) - 1);
  meta.avg_kmh = e.avg_kmh;
  meta.max_kmh = e.max_kmh;
  trip_storage::writeMeta(e.id, meta);
  trip_storage::clearInProgress();
  trip_storage::markSyncStatus(e.id, trip_storage::STATUS_UNSENT);
}

// If the device reset mid-trip, in_progress.txt still names a trip left
// with start-only meta. Rebuild end-meta from the on-flash fixes so it
// syncs as a normal trip, not ets=0/km=0/unknown (PicoB try_resume).
static void finalizeInterruptedTrip() {
  char id[trip_storage::TRIP_ID_MAX];
  if (trip_storage::readInProgress(id, sizeof(id)) == 0) return;  // clean shutdown

  if (trip_storage::tripNpts(id) < 2) {
    Serial.printf("[TRIP] interrupted %s too short — discarding\n", id);
    trip_storage::deleteTrip(id);
    trip_storage::clearInProgress();
    return;
  }

  sync_codec::Fix buf[16];
  sync_codec::Fix first{}, last{}, prev{};
  bool   haveFirst = false, havePrev = false;
  double km = 0.0;
  float  sumSpd = 0.0f, maxSpd = 0.0f, prevSpd = 0.0f;
  uint32_t count = 0;
  size_t from = 0;
  while (true) {
    size_t got = trip_storage::readFixesRange(id, from, 16, buf);
    if (got == 0) break;
    for (size_t i = 0; i < got; i++) {
      const sync_codec::Fix& f = buf[i];
      if (!haveFirst) { first = f; haveFirst = true; prevSpd = f.spd > 0 ? f.spd : 0.0f; }
      if (havePrev) km += TripTracker::distM(prev.lat, prev.lon, f.lat, f.lon) / 1000.0;
      // Sustained-max: min(prev,cur) so a doppler spike isn't the max.
      float sustained = (f.spd < prevSpd) ? f.spd : prevSpd;
      if (sustained > maxSpd) maxSpd = sustained;
      prevSpd = f.spd;
      sumSpd += f.spd;
      count++;
      prev = f; havePrev = true; last = f;
    }
    from += got;
    if (got < 16) break;
  }
  if (count < 2) {  // too little survived parsing
    trip_storage::deleteTrip(id);
    trip_storage::clearInProgress();
    return;
  }

  float     avg  = sumSpd / (float)count;
  MoveClass type = TripTracker::classifyWithMax(avg, maxSpd);

  trip_storage::Meta meta = {};
  strncpy(meta.device, g_deviceId,   sizeof(meta.device) - 1);
  strncpy(meta.hwid,   g_deviceHwid, sizeof(meta.hwid)   - 1);
  strncpy(meta.id,     id,           sizeof(meta.id)     - 1);
  meta.sts     = first.ts;
  meta.ets     = last.ts;
  meta.slat    = first.lat;
  meta.slon    = first.lon;
  meta.elat    = last.lat;
  meta.elon    = last.lon;
  meta.km      = (float)km;
  meta.dur_s   = (last.ts > first.ts) ? (uint32_t)(last.ts - first.ts) : 1u;
  strncpy(meta.type, moveClassName(type), sizeof(meta.type) - 1);
  meta.avg_kmh = avg;
  meta.max_kmh = maxSpd;
  trip_storage::writeMeta(id, meta);
  trip_storage::clearInProgress();
  trip_storage::markSyncStatus(id, trip_storage::STATUS_UNSENT);

  Serial.printf("[TRIP] recovered interrupted %s: %u pts %.3f km %us %s\n",
                id, (unsigned)count, km, (unsigned)meta.dur_s, moveClassName(type));
}

void setup() {
  Serial.begin(115200);
  delay(2000);
  Serial.println();
  Serial.println("=== ESP32-C3 LoRa+WiFi Chat + GPS ===");

  Chat.begin();             // also calls LittleFS.begin
  loadDeviceId();           // overrides g_deviceId from /device_id.txt if present
  computeHwid();            // factory-burned chip MAC -> g_deviceHwid (hex)
  Serial.printf("device_hwid=%s\n", g_deviceHwid);
  trip_storage::begin();
  finalizeInterruptedTrip();   // salvage a trip the last reset cut short
  Sync.begin();
  Tracker.begin(g_deviceId);
  Presence.begin(g_deviceHwid, g_deviceId);
  Net.begin();
  Web.begin();
  Gps.begin();
  g_radioOk = Radio.begin();

  // One-shot boot announce so the Pi 5 "+ Add device" listen window can
  // discover unknown devices and rename them via the existing RENAME
  // protocol. Best-effort; if the radio failed to start we just skip it.
  sendDeviceAnnounce();
}

void loop() {
  Net.loop();
  Web.loop();

  // ---- GPS pipeline: parse NMEA, emit, feed tracker ----
  sync_codec::Fix fix;
  if (Gps.tryReadFix(&fix)) {
    broadcastGps(fix);

    TripStart ts_msg;
    TripEnd   te_msg;
    TrackerEvent ev = Tracker.update(fix, &ts_msg, &te_msg);

    if (ev == EV_TRIPSTART) {
      persistTripStart(ts_msg);
      // Retroactive prefix: any IDLE fixes that the tracker buffered
      // while motion was building up belong to this trip. The trigger
      // fix comes last in the polyline; the buffered fixes come first
      // so the trip's start coord matches actual departure.
      const size_t n = Tracker.precedingCount();
      for (size_t i = 0; i < n; i++) {
        trip_storage::writeFix(ts_msg.id, Tracker.precedingFix(i));
      }
      trip_storage::writeFix(ts_msg.id, fix);
      broadcastTripStart(ts_msg);
    } else if (ev == EV_TRIPEND) {
      if (te_msg.confirmed) {
        persistTripEnd(te_msg);
        broadcastTripEnd(te_msg);
        // Announce immediately so the Pi can pull the data while we're
        // still on the air; Sync.tick retries every 5 min if needed.
        Sync.announce();
      } else {
        // False-start: trigger fired but no real motion materialised
        // (GPS multipath burst followed by stop). Wipe the files and
        // skip the broadcast — keeps the hub DB and sync queue clean.
        Serial.printf("[TRIP] discarding unconfirmed %s (km=%.3f max=%.2f)\n",
                      te_msg.id, te_msg.km, te_msg.max_kmh);
        trip_storage::deleteTrip(te_msg.id);
        trip_storage::clearInProgress();
      }
    } else if (Tracker.inTrip()) {
      trip_storage::writeFix(Tracker.tripId(), fix);
    }

    // Cadence selection by class (smoothed speed + hysteresis)
    if (Tracker.inTrip()) {
      float smoothed = pushAndSmoothSpd(fix.spd);
      MoveClass nc = pickClass(smoothed, g_class);
      if (nc != g_class) {
        g_class = nc;
        Gps.setIntervalMs(intervalForClass(g_class));
        Serial.printf("[cadence] class=%s interval=%lums\n",
                      moveClassName(g_class),
                      (unsigned long)Gps.getIntervalMs());
      }
    } else if (g_class != CLASS_IDLE) {
      g_class = CLASS_IDLE;
      Gps.setIntervalMs(intervalForClass(CLASS_IDLE));
      g_recentN = g_recentIdx = 0;
    }
  }

  // ---- LoRa RX: sync first, then chat filter, then drop ----
  if (g_radioOk) {
    char text[251];
    LoraRxResult meta;
    if (Radio.pollReceive(text, sizeof(text), &meta)) {
      Serial.printf("[RX] '%s' (rssi=%d snr=%.1f)\n",
                    text, meta.rssi, meta.snr);
      // DEVICE: must be checked first — rename matches reboot the node;
      // hello/renamed echoes are silently consumed. Either way, the
      // packet doesn't fall through to chat or sync layers.
      if (handleDeviceMessage(text, meta.rssi)) {
        // unreachable for rename; consumed for hello/renamed
      } else if (handleQposMessage(text)) {
        // on-demand position query — fire-and-forget GPS broadcast
      } else if (handleWhoMessage(text)) {
        // presence probe — re-announce DEVICE
      } else if (Sync.onMessage(text)) {
        // handled by sync layer
      } else if (strncmp(text, "CHAT:", 5) == 0) {
        Chat.addRx(text + 5, meta.rssi, meta.snr);
        Chat.flushIfNeeded();
      }
    }
  }
  Sync.tick(millis());

  uint32_t now = millis();

  // Liveness heartbeat: re-announce DEVICE every 60 s so peers + the hub
  // keep us "online". touchSelf keeps our own roster entry fresh.
  static uint32_t lastAnnounce = 0;
  if (now - lastAnnounce >= 60000UL) {
    lastAnnounce = now;
    sendDeviceAnnounce();
    Presence.touchSelf(now);
  }

  static uint32_t lastTick = 0;
  if (now - lastTick >= 5000) {
    lastTick = now;
    Serial.printf("[heartbeat] radio=%s wifi=%s%s clients=%u/%d uptime=%lus "
                  "chat_msgs=%u gps=%s nmea_chars=%lu fix_sentences=%lu "
                  "csum_fail=%lu class=%s in_trip=%s\n",
                  g_radioOk ? "OK" : "FAIL",
                  Net.isUp() ? "up" : "DOWN",
                  Net.isSleeping() ? "(sleep)" : "",
                  Net.clientCount(), wifi::MAX_CLIENTS,
                  (unsigned long)(now / 1000),
                  (unsigned)Chat.count(),
                  Gps.hasFix() ? "fix" : "no_fix",
                  (unsigned long)Gps.charsProcessed(),
                  (unsigned long)Gps.sentencesWithFix(),
                  (unsigned long)Gps.failedChecksum(),
                  moveClassName(g_class),
                  Tracker.inTrip() ? "yes" : "no");
  }
}

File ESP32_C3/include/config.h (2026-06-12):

#pragma once
#include <stddef.h>
#include <stdint.h>

#ifndef DEVICE_ID
#define DEVICE_ID "esp32-c3"
#endif

// Runtime-mutable device id. Initialised to the compile-time DEVICE_ID at
// startup, then overridden from /device_id.txt if a rename has been
// persisted. All runtime LoRa / web / sync code should reference
// g_deviceId, not DEVICE_ID directly — DEVICE_ID is the boot-time fallback.
extern char g_deviceId[16];

// Permanent hardware id, hex-encoded ESP32 chip MAC. Populated in
// computeHwid() during setup(). Other translation units (sync_manager
// etc.) read this when constructing wire payloads.
extern char g_deviceHwid[16];

namespace pins {
constexpr int LORA_SCK  = 4;
constexpr int LORA_MISO = 5;
constexpr int LORA_MOSI = 6;
constexpr int LORA_NSS  = 7;
constexpr int LORA_RST  = 10;
constexpr int LORA_DIO0 = 3;
constexpr int GPS_RX    = 20;
constexpr int GPS_TX    = 21;
}

namespace rf {
// 434.0, not 433 -- legacy Pico lora.py hard-codes FRF=0x6C8000
// which decodes to 434.0 MHz exactly. The "433 MHz" label there
// is loose terminology; both ends must match the actual RF carrier.
constexpr float   FREQ_MHZ = 434.0f;
constexpr float   BW_KHZ   = 125.0f;
// SF must match Pico A (Hub_Server_Firmware/lora.py) and Pico B
// (PicoB/runtime.py) exactly. Currently SF9 — chosen for sync speed
// while a large backlog drains; bump to SF11 for max range when sync
// is quiet. RadioLib handles LDRO automatically.
constexpr uint8_t SF       = 9;
constexpr uint8_t CR       = 5;
constexpr uint8_t SYNC     = 0x34;
constexpr uint8_t PREAMBLE = 8;
constexpr int8_t  POWER    = 20;
}

// AES-128-ECB key shared with PicoB (config.py:LORA_KEY) and Pico A.
// Must match exactly across every node.
namespace crypto_cfg {
constexpr uint8_t AES_KEY[16] =
    {'L','o','R','a','M','e','s','h','D','e','m','o','K','e','y','1'};
constexpr size_t  BLOCK = 16;
}

constexpr uint32_t TX_PERIOD_MS = 5000;

namespace wifi {
constexpr const char* SSID        = "LoraWan";
constexpr const char* PASSWORD    = "ChangeMe-LoRa24";
constexpr int         CHANNEL     = 6;
constexpr int         MAX_CLIENTS = 2;
}

// ----- GPS cadence + class hysteresis (match PicoB's runtime.py) ------
namespace gps_cfg {
constexpr uint32_t IDLE_INTERVAL_MS    = 60000;
constexpr uint32_t WALKING_INTERVAL_MS = 15000;
constexpr uint32_t CYCLING_INTERVAL_MS = 10000;
constexpr uint32_t DRIVING_INTERVAL_MS     = 10000;

constexpr float WALK_TO_CYCLE_UP   = 8.0f;
constexpr float CYCLE_TO_WALK_DOWN = 6.0f;
constexpr float CYCLE_TO_DRIVING_UP    = 27.0f;
constexpr float DRIVING_TO_CYCLE_DOWN  = 23.0f;

constexpr size_t SPEED_SMOOTH_N = 5;   // smoothed speed window
}

// ----- Trip tracker thresholds (match PicoB's trip_tracker.py) -----
namespace trip_cfg {
constexpr float    MOVE_SPEED_KMH = 5.0f;
constexpr uint32_t MOVE_HOLD_S    = 30;
constexpr float    START_DIST_M   = 100.0f;
constexpr float    END_DIST_M     = 15.0f;
// Number of accepted fixes the tracker has to see since boot before it
// will believe a trip-start trigger. NEO-7M wanders 50-200 m and
// reports phantom 1-5 km/h Doppler speed during the first few fixes
// after a cold lock; without this gate that drift fires `far` or
// `sustained` and produces a 6 min ghost walking trip on a desk.
constexpr uint32_t MIN_FIXES_BEFORE_START = 5;
// Retroactive trip-start: ring buffer of the most recent IDLE fixes
// that showed motion (spd >= TRIP_LOW_SPEED_KMH). When the trigger
// finally fires, these fixes become the trip's prefix so the start
// coord matches actual departure rather than the trigger moment.
constexpr float    TRIP_LOW_SPEED_KMH = 2.0f;
constexpr size_t   MOTION_BUFFER_MAX  = 6;   // ~60 s at 10 s cadence
// Post-trip sanity check: a trip that ends without confirming the
// start trigger conditions (no distance + no sustained speed) is
// almost certainly a false-start. Discard from flash + skip persist
// + broadcast. Thresholds mirror PicoB's trip_tracker.py constants.
constexpr float    MIN_REAL_TRIP_M       = 100.0f;
constexpr float    MIN_REAL_TRIP_MAX_KMH = 5.0f;

constexpr uint32_t STOP_S_WALKING = 120;
constexpr uint32_t STOP_S_CYCLING =  60;
constexpr uint32_t STOP_S_DRIVING     = 300;

constexpr float CLASS_WALK_MAX = 7.0f;
constexpr float CLASS_BIKE_MAX = 25.0f;
}

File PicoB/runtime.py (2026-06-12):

"""
runtime.py - Pico B device runtime.

The full node-side program: LoRa radio + AES, GPS module, trip-tracker
state machine, sync protocol (SYNC/Q*/R*/ACK), chat send/receive,
QPOS/WHO presence handlers, watchdog/retry, cadence-by-class.

main.py imports this and calls chat() on boot (the function name is
historical — chat() now runs the whole node). Pico A pins (old card):
    SCK=GPIO2, MOSI=GPIO3, MISO=GPIO4, NSS=GPIO5, RST=GPIO22, DIO0=GPIO26
Radio settings (must match the bridge): 433 MHz, SF9, BW125, CR4/5,
sync 0x34, CRC on. AES-128-ECB with the network key in config.py.

Hub-side counterpart lives in Hub_Server/hub.py.
"""

import time
import sys
import select
import json
from machine import SPI, Pin
import cryptolib

import gps_module
import trip_tracker
import trip_storage
import sync_codec


# ============================================================
# Device identity (multi-device-friendly)
# ============================================================
# DEVICE_ID is loaded from device_id.txt on flash if present (so the Pi
# can rename the device over LoRa via the DEVICE: protocol). Falls back
# to the compile-time default below for fresh / unrecovered devices.
_DEFAULT_DEVICE_ID = "raspberry-pico"
DEVICE_ID_FILE     = "device_id.txt"

def _load_device_id():
    try:
        with open(DEVICE_ID_FILE, "r") as f:
            new_id = f.read().strip()
        if (new_id and len(new_id) < 16 and
                all((c.isalpha() or c.isdigit() or c in "_-") for c in new_id)):
            return new_id
    except Exception:
        pass
    return _DEFAULT_DEVICE_ID

DEVICE_ID = _load_device_id()
print("device_id={}".format(DEVICE_ID))

# Permanent hardware id, hex-encoded. RP2040 burns 8 bytes of unique
# silicon id at the factory — survives any flash erase and is globally
# unique. The Pi 5 uses this to address rename commands so the
# (renameable) device_id name and the (immutable) device identity stay
# clearly separate on the wire and in the DB.
try:
    from machine import unique_id as _machine_unique_id
    DEVICE_HWID = _machine_unique_id().hex()
except Exception as _e:
    # Should never happen on RP2040, but keep the device functional.
    DEVICE_HWID = "0" * 16
    print("[WARN] unique_id failed:", _e)
print("device_hwid={}".format(DEVICE_HWID))

# Local audit log of every completed trip on this Pico.  Best-effort, no
# rotation - if you walk a lot, prune manually via Thonny.
TRIPS_LOG_FILE = "trips_log.json"

# GPS poll cadence by movement class (seconds).  The save cadence directly
# determines how dense the .gps file will be - faster cadences give a
# smoother polyline on the map but cost a bit more battery and flash.
#
# IDLE is much slower since there's nothing useful to record.
CADENCE_BY_CLASS = {
    "idle":    60,
    "walking": 15,
    "cycling": 10,
    "driving": 10,
}

# Hysteresis bands so a speed bouncing around a boundary doesn't cause us
# to switch cadence on every fix.  Once classified, we only step UP to a
# higher class when speed exceeds upper_band, and step DOWN when speed
# drops below lower_band.
#
# Class boundaries today: walking < 7 < cycling < 25 <= driving.
# We use +/- 1 km/h margins.
WALK_TO_CYCLE_UP      = 8.0
CYCLE_TO_WALK_DOWN    = 6.0
CYCLE_TO_DRIVING_UP   = 27.0
DRIVING_TO_CYCLE_DOWN = 23.0


def pick_class(spd, prev_class):
    """Pick movement class with hysteresis to avoid thrashing.
    spd is in km/h.  prev_class is the previously selected class
    ("walking"/"cycling"/"driving"/"idle"), used to decide the threshold."""
    if prev_class == "walking":
        if spd >= WALK_TO_CYCLE_UP:
            return "cycling" if spd < CYCLE_TO_DRIVING_UP else "driving"
        return "walking"
    if prev_class == "cycling":
        if spd >= CYCLE_TO_DRIVING_UP:
            return "driving"
        if spd < CYCLE_TO_WALK_DOWN:
            return "walking"
        return "cycling"
    if prev_class == "driving":
        if spd < DRIVING_TO_CYCLE_DOWN:
            # Could drop straight to walking if very slow
            if spd < CYCLE_TO_WALK_DOWN:
                return "walking"
            return "cycling"
        return "driving"
    # First call (prev_class None or "idle") - pick by static thresholds
    if spd >= CYCLE_TO_DRIVING_UP:
        return "driving"
    if spd >= WALK_TO_CYCLE_UP:
        return "cycling"
    return "walking"


# Standalone mode: when True, skip stdin/REPL handling and don't draw a
# prompt.  Set this from main.py before calling chat() so the Pico can
# run on battery power with no host attached.
STANDALONE = False


# ============================================================
# Encryption (AES-128 ECB) - MUST match key on Pico A's main.py
# ============================================================
LORA_KEY = b"LoRaMeshDemoKey1"   # exactly 16 bytes - must match Pico A's main.py
_AES_ECB = 1
_BLOCK   = 16

def _pad(data):
    n = _BLOCK - (len(data) % _BLOCK)
    return data + bytes([n]) * n

def _unpad(data):
    if not data or len(data) % _BLOCK != 0:
        return None
    n = data[-1]
    if n < 1 or n > _BLOCK:
        return None
    for i in range(1, n + 1):
        if data[-i] != n:
            return None
    return data[:-n]

def encrypt(plaintext):
    if isinstance(plaintext, str):
        plaintext = plaintext.encode("utf-8")
    cipher = cryptolib.aes(LORA_KEY, _AES_ECB)
    return cipher.encrypt(_pad(plaintext))

def decrypt(blob):
    """Returns plaintext bytes or None on failure."""
    if not isinstance(blob, (bytes, bytearray)):
        return None
    if len(blob) < _BLOCK or len(blob) % _BLOCK != 0:
        return None
    try:
        cipher = cryptolib.aes(LORA_KEY, _AES_ECB)
        padded = cipher.decrypt(bytes(blob))
    except Exception:
        return None
    return _unpad(padded)


# ============================================================
# GPS message helper
# ============================================================
# When user types:  gps 50.0755 14.4378
#                   gps 50.0755 14.4378 205.3 4.2
# we wrap as JSON:  GPS:{"lat":50.0755,"lon":14.4378,"alt":205.3,"spd":4.2,"ts":<unix>}
def format_gps_message(parts):
    """parts: list of strings after the 'gps' keyword.
    Returns the formatted message string, or raises ValueError.

    Wire payload is intentionally minimal — the only thing GPS:
    broadcasts feed is the live map dot, which needs identity +
    position + timestamp. Altitude / speed live in the trip log
    (TRIPEND / RPTS fix data), not in periodic broadcasts. Saves
    ~40 B per packet which translates to ~150 ms less airtime at SF9.
    """
    if len(parts) < 2:
        raise ValueError("usage: gps <lat> <lon>")
    obj = {"hwid": DEVICE_HWID,
           "lat":  float(parts[0]),
           "lon":  float(parts[1]),
           "ts":   int(time.time())}
    return "GPS:" + json.dumps(obj, separators=(',', ':'))
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
